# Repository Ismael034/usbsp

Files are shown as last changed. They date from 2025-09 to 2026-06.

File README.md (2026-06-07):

# USBsp

Have you ever tried to plug a USB device into a computer that has USB restrictions enabled? It's frustrating, isn't it? You can't use your USB devices, and you have no way to bypass the restrictions. But what if I told you that you could spoof the USB identifiers so you bypass these restrictions? That's where USBsp comes in.

Here is your solution!

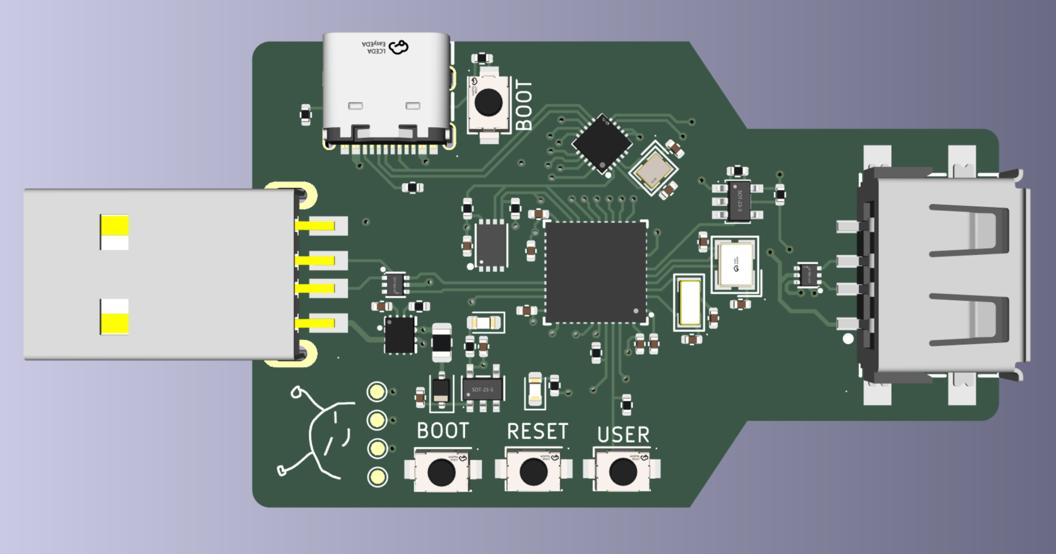
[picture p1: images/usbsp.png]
USBsp hardware


USBsp is a USB device that can spoof the USB identifiers of any device you want. It is based on the CH32V203 and CH572D microcontrollers. With USBsp, you can easily bypass USB restrictions and use your USB devices without any issues.

## Features

- Spoofs basic USB descriptor fields: VID, PID, bcdDevice, manufacturer, product and serial.
- Stores the spoofed descriptor settings in EEPROM.
- WebUSB control panel for changing settings from a Chromium-based browser.
- Can read descriptor-like values from the currently connected downstream USB device and use them as a starting point.
- Basic live packet capture.
- Simple HID keyboard/mouse visualizers.

## Building

The required toolchain is alredy included. It is a custom toolchain made by WCH, downloaded from [here](https://www.mounriver.com/download). This toolchain constains custom targets for their MCUs. Other toolchains (like xpack) have not been tested.

### Clone the repository and add the toolchain to the path

```
git clone https://github.com/Ismael034/usbsp.git
cd usbsp
export PATH=$PWD/toolchain/bin/:$PATH
```

### Configure meson

```
meson setup build-ch32v203 --cross-file ch32v203/ch32v203-cross.ini
meson setup build-ch572d --cross-file ch572d/ch572d-cross.ini
```

### Build with ninja

```
ninja -C build-ch32v203 ch32v203/ch32v203.hex
ninja -C build-ch572d ch572d/ch572d.hex
```

If everything goes well, you'll end up with two .hex files – one for each MCU.

## Flashing

To flash the firmware to your MCU, you can use one of the following tools:

- [WCH-LinkUtility](https://www.wch.cn/downloads/wch-linkutility_zip.html)
- [wlink](https://github.com/ch32-rs/wlink/)
- [OpenOCD](https://openocd.org/)

```
wlink flash ./build-ch32v203/ch32v203/ch32v203.hex
wlink flash ./build-ch572d/ch572d/ch572d.hex
```

## Tests

It is also possible to build a test firmware, which will test hardware funcionality like EEPROM access, USBD, USBH, buttons, etc. You can build it using a predefined custom target.

```
ninja -C build-ch32v203 ch32v203/ch32v203_test.hex
```

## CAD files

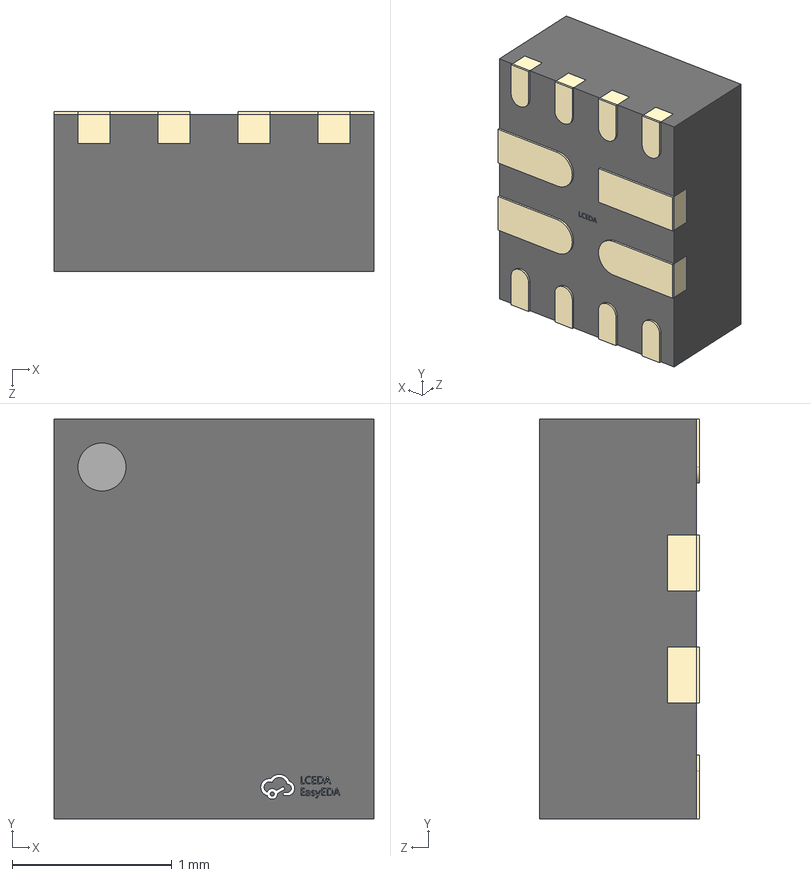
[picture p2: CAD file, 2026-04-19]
hardware/dev/usb_sp_fp_dev/usb_sp_model_dev/VQFN-HR-12_L2.5-W2.0-P0.50-BL.step
2.00 x 2.50 x 1.00 mm

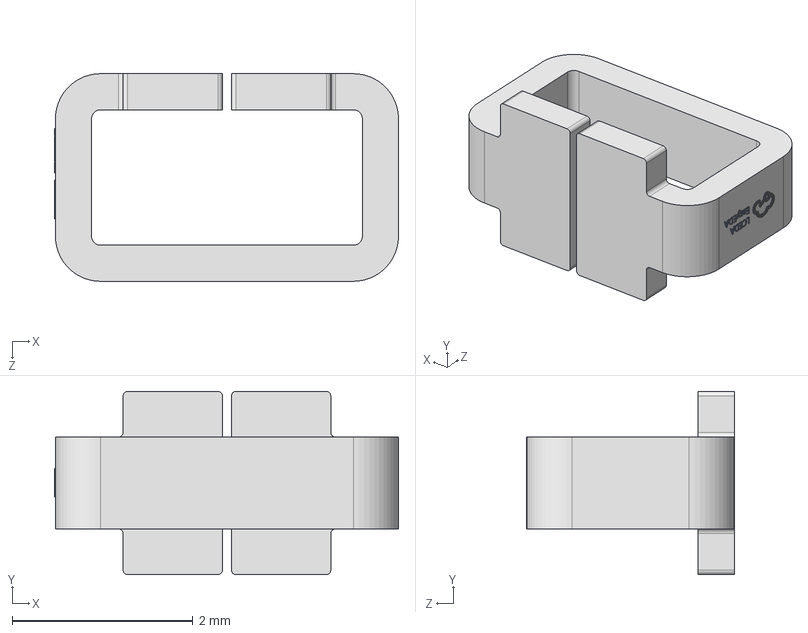
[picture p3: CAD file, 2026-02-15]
hardware/dev/usb_sp_fp_dev/usb_sp_model_dev/TESTPOINT-SMD_L3.8-W2.0_RH-5019.step
3.81 x 2.03 x 2.30 mm

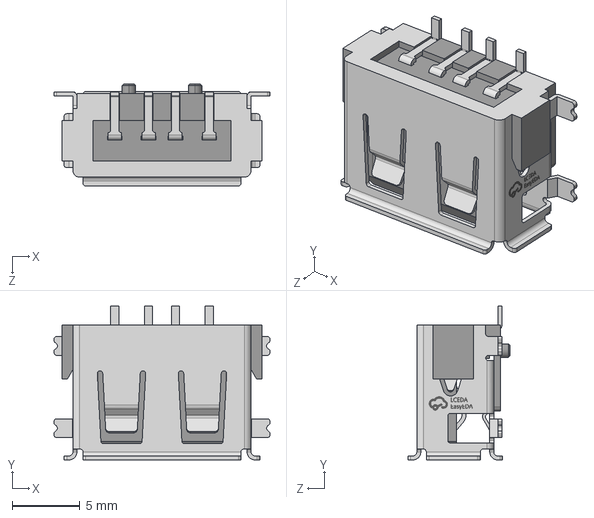
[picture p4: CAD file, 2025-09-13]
hardware/usb_sp_fp/usb_sp_model/USB-A-SMD_10.0-QTJ6.3.step
16.0 x 11.4 x 7.55 mm

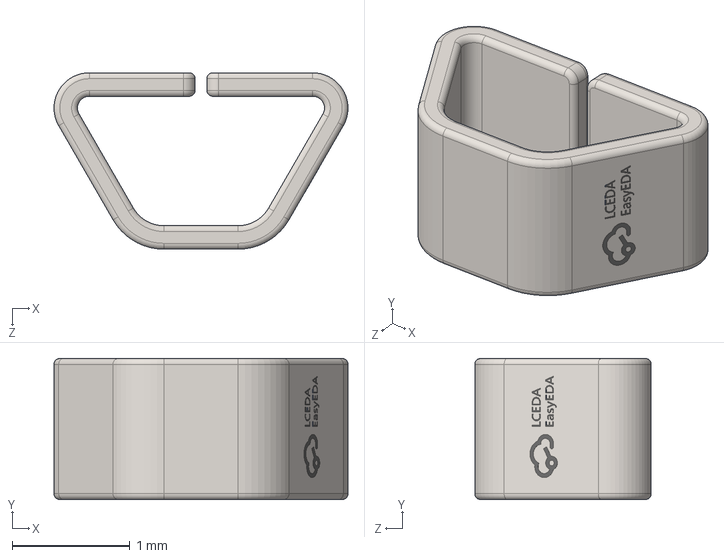
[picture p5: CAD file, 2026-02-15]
hardware/dev/usb_sp_fp_dev/usb_sp_model_dev/SMD_RH-5015.step
2.50 x 1.20 x 1.50 mm

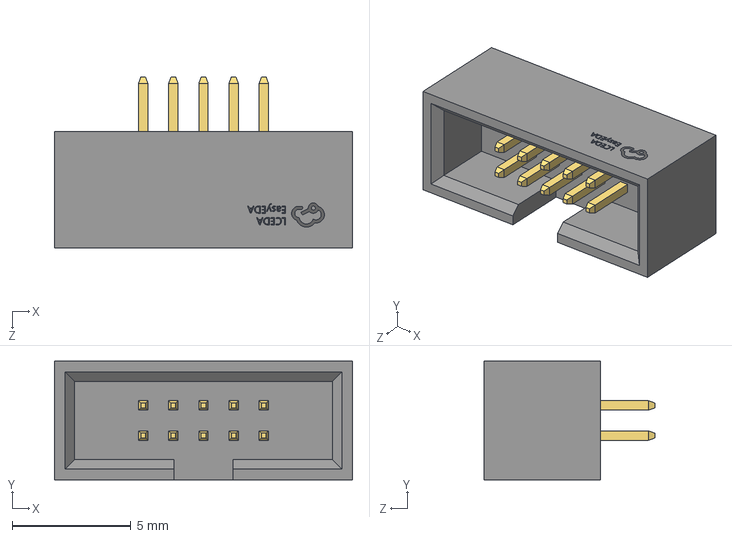
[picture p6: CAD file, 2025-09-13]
hardware/usb_sp_fp/usb_sp_model/CONN-TH_10P-P1.27_HX-JN1.27-2X5P-ZZ-H4.9.step
12.6 x 5.00 x 7.20 mm

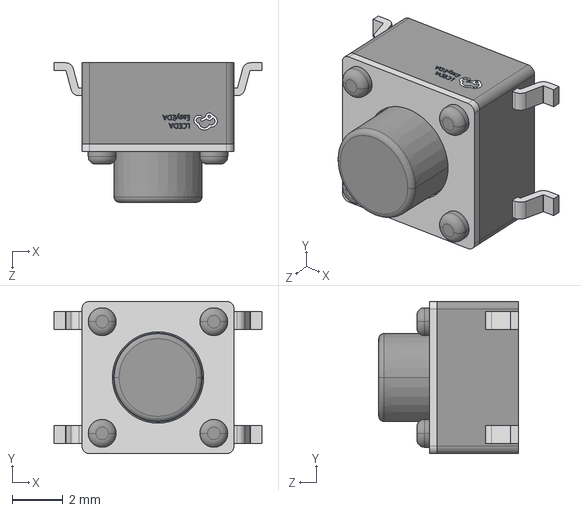
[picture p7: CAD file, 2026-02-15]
hardware/dev/usb_sp_fp_dev/usb_sp_model_dev/SW-SMD_4P-L6.0-W6.0-P4.50-LS8.2.step
8.20 x 6.00 x 5.50 mm

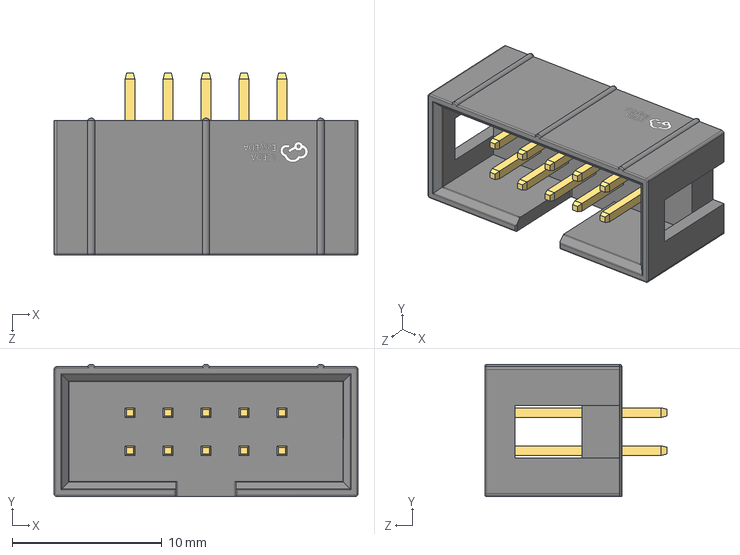
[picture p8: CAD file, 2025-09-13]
hardware/usb_sp_fp/usb_sp_model/IDC-TH_10P-P2.54_C5665.step
20.3 x 8.85 x 12.2 mm

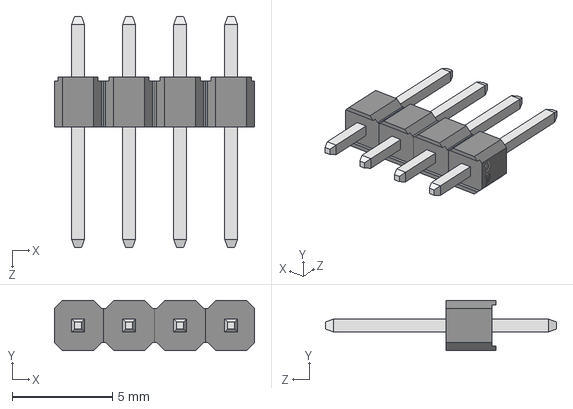
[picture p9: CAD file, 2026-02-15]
hardware/dev/usb_sp_fp_dev/usb_sp_model_dev/HDR-TH_4P-HX-PH254-01-04-Z-L11.5.step
9.97 x 2.50 x 11.5 mm

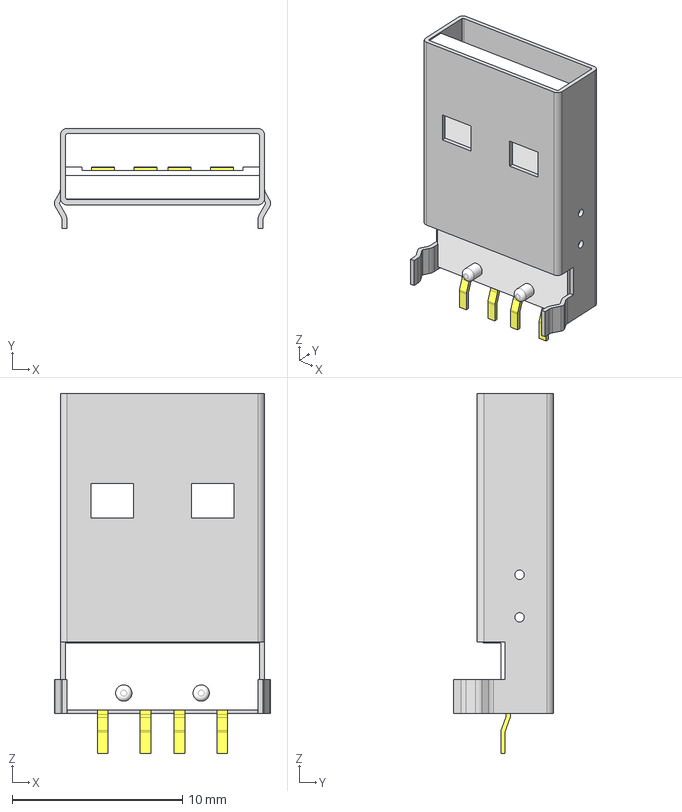
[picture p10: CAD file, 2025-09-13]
hardware/usb_sp_fp/usb_sp_model/USB-A-SMD_917-181A102ES60200.step
12.7 x 5.89 x 21.1 mm
USB-AM-S-SM1_S
USB-AM-S-W-SM1_B
USB-AM-S-SM1_P

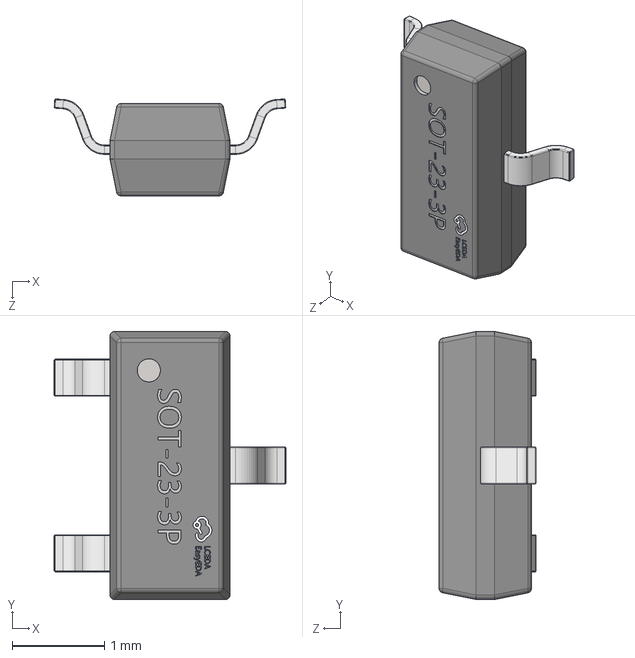
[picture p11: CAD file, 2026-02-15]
hardware/dev/usb_sp_fp_dev/usb_sp_model_dev/SOT-23-3_L2.9-W1.3-P1.90-LS2.4-BR.step
2.51 x 2.90 x 1.05 mm

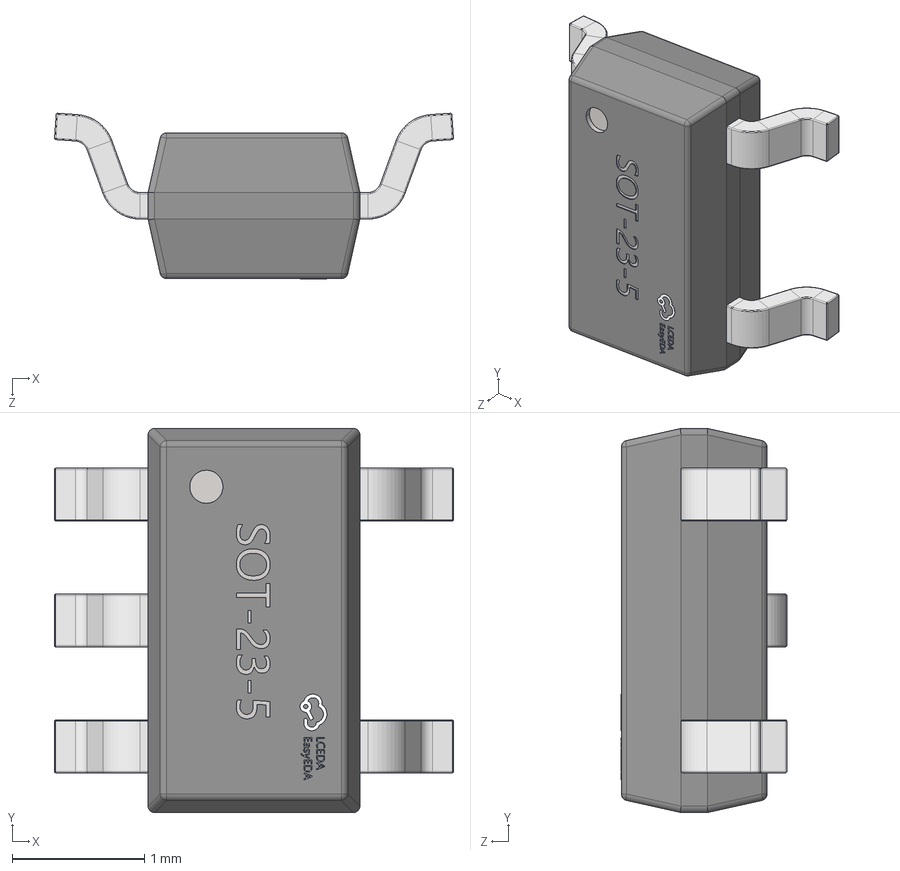
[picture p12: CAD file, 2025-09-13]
hardware/usb_sp_fp/usb_sp_model/SOT-23-5_L3.0-W1.7-P0.95-LS2.8-BL.step
3.01 x 2.90 x 1.25 mm

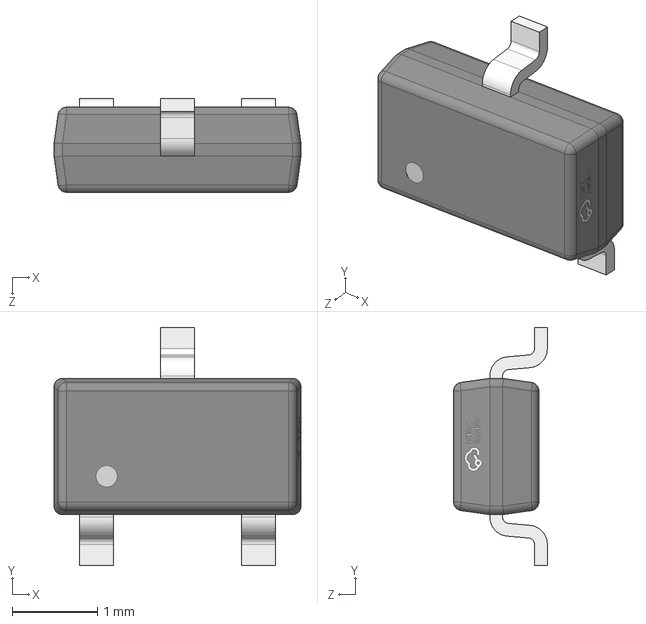
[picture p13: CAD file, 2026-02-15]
hardware/dev/usb_sp_fp_dev/usb_sp_model_dev/SOT-23-3_L2.9-W1.6-P1.90-LS2.8-BR.step
2.90 x 2.80 x 1.10 mm

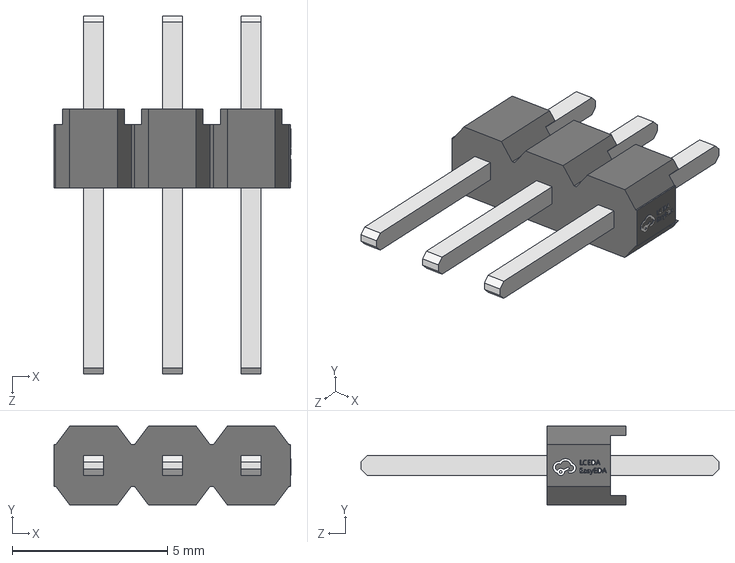
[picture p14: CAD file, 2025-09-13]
hardware/usb_sp_fp/usb_sp_model/HDR-TH_3P-P2.54-V-M.step
7.63 x 2.54 x 11.5 mm

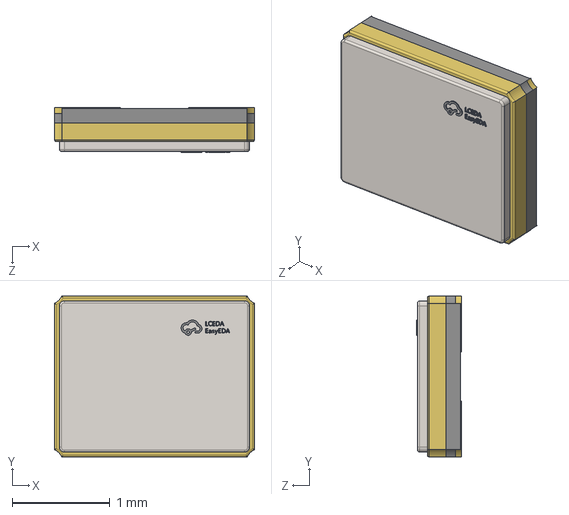
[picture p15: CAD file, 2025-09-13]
hardware/usb_sp_fp/usb_sp_model/CRYSTAL-SMD_4P-L2.0-W1.6-BL.step
2.05 x 1.65 x 0.46 mm

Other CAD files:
hardware/usb_sp_fp/usb_sp_model/SOT-666-6_L1.6-W1.2-P0.50-LS1.6-BL.step
hardware/usb_sp_fp/usb_sp_model/USB-C-SMD_KH-TYPE-C-16P.step
hardware/usb_sp_fp/usb_sp_model/CRYSTAL-SMD_4P-L3.2-W2.5-BL.step
hardware/usb_sp_fp/usb_sp_model/CRYSTAL-SMD_L3.2-W1.5-1.step
hardware/usb_sp_fp/usb_sp_model/OSC-SMD_4P-L3.2-W2.5-BL.step
hardware/usb_sp_fp/usb_sp_model/QFN-20_L3.0-W3.0-P0.40-TL-EP1.7.step
hardware/usb_sp_fp/usb_sp_model/SW-SMD_L3.9-W3.0-P4.45.step
hardware/usb_sp_fp/usb_sp_model/TQFN-48_L7.0-W7.0-P0.50-BL-EP5.5.step
hardware/usb_sp_fp/usb_sp_model/UDFN-8_L3.0-W2.0-P0.50-BL-EP-3.step

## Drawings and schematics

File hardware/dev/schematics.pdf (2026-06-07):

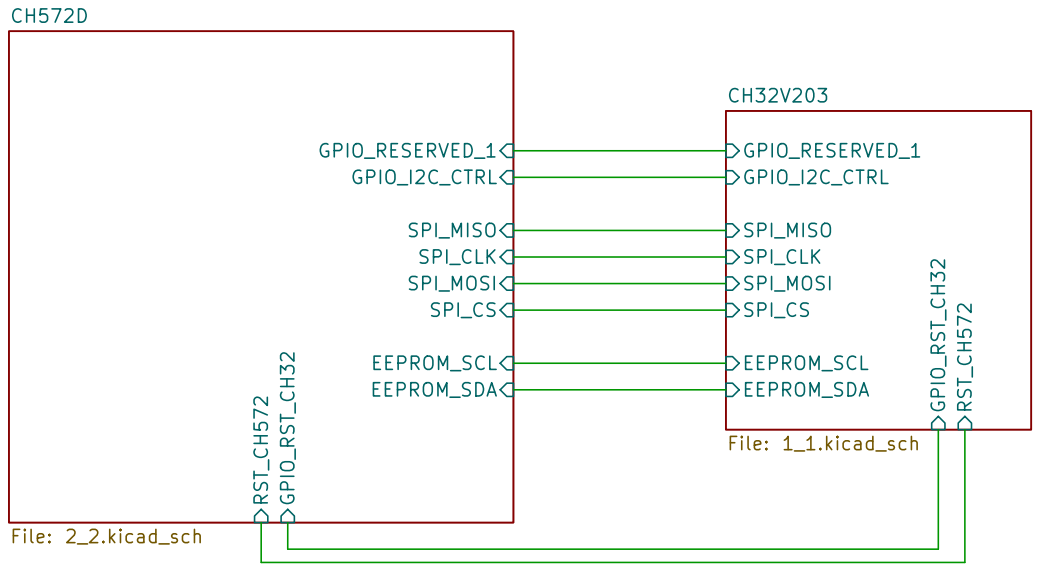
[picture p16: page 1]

Size: A4 | Rev:
KiCad E.D.A. 10.0.3 | Id: 3/3

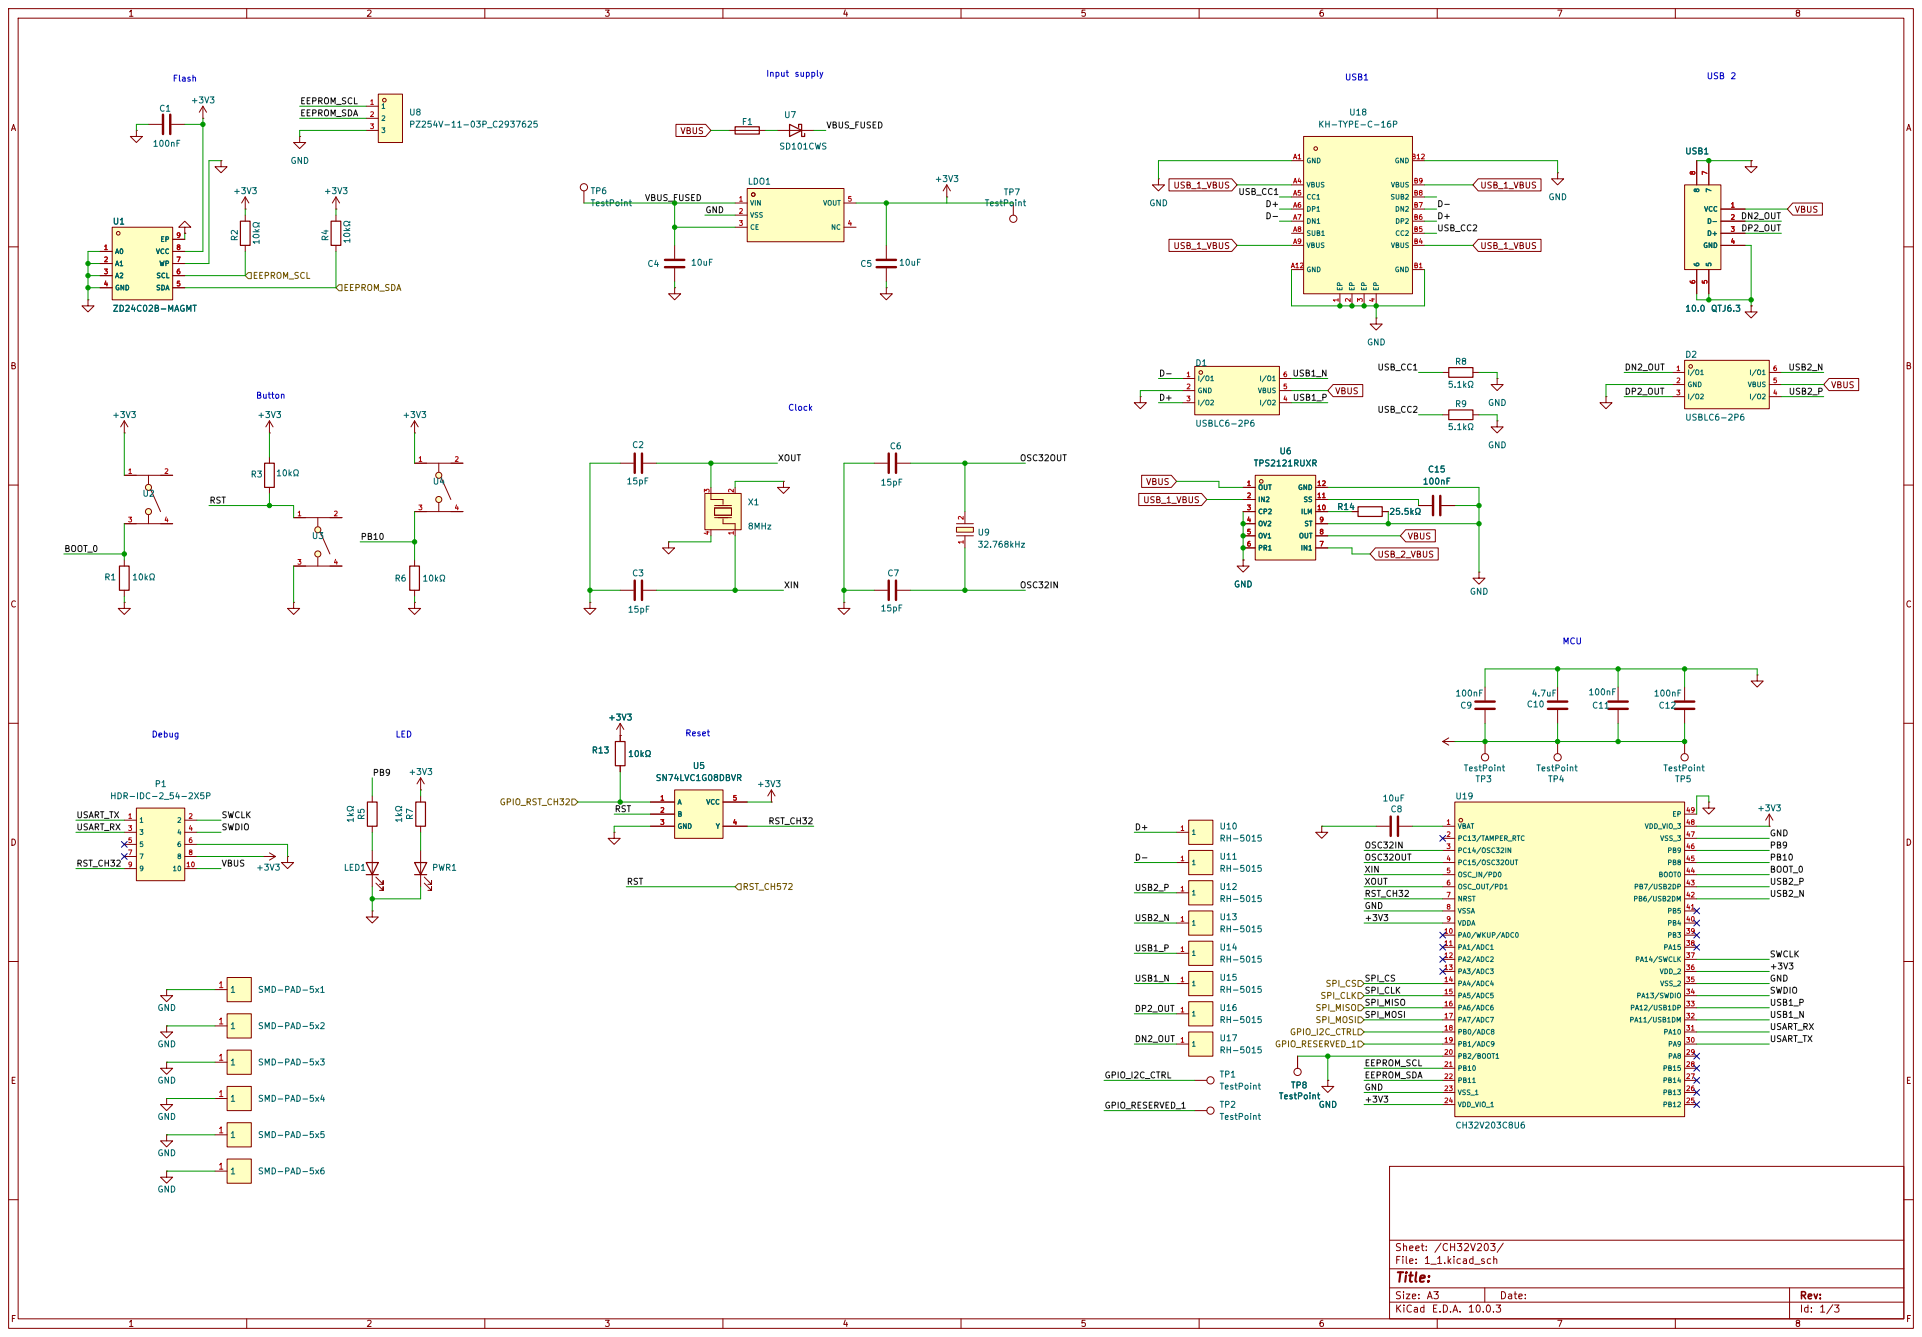
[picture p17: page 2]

Input supply Clock Button Debug
Flash

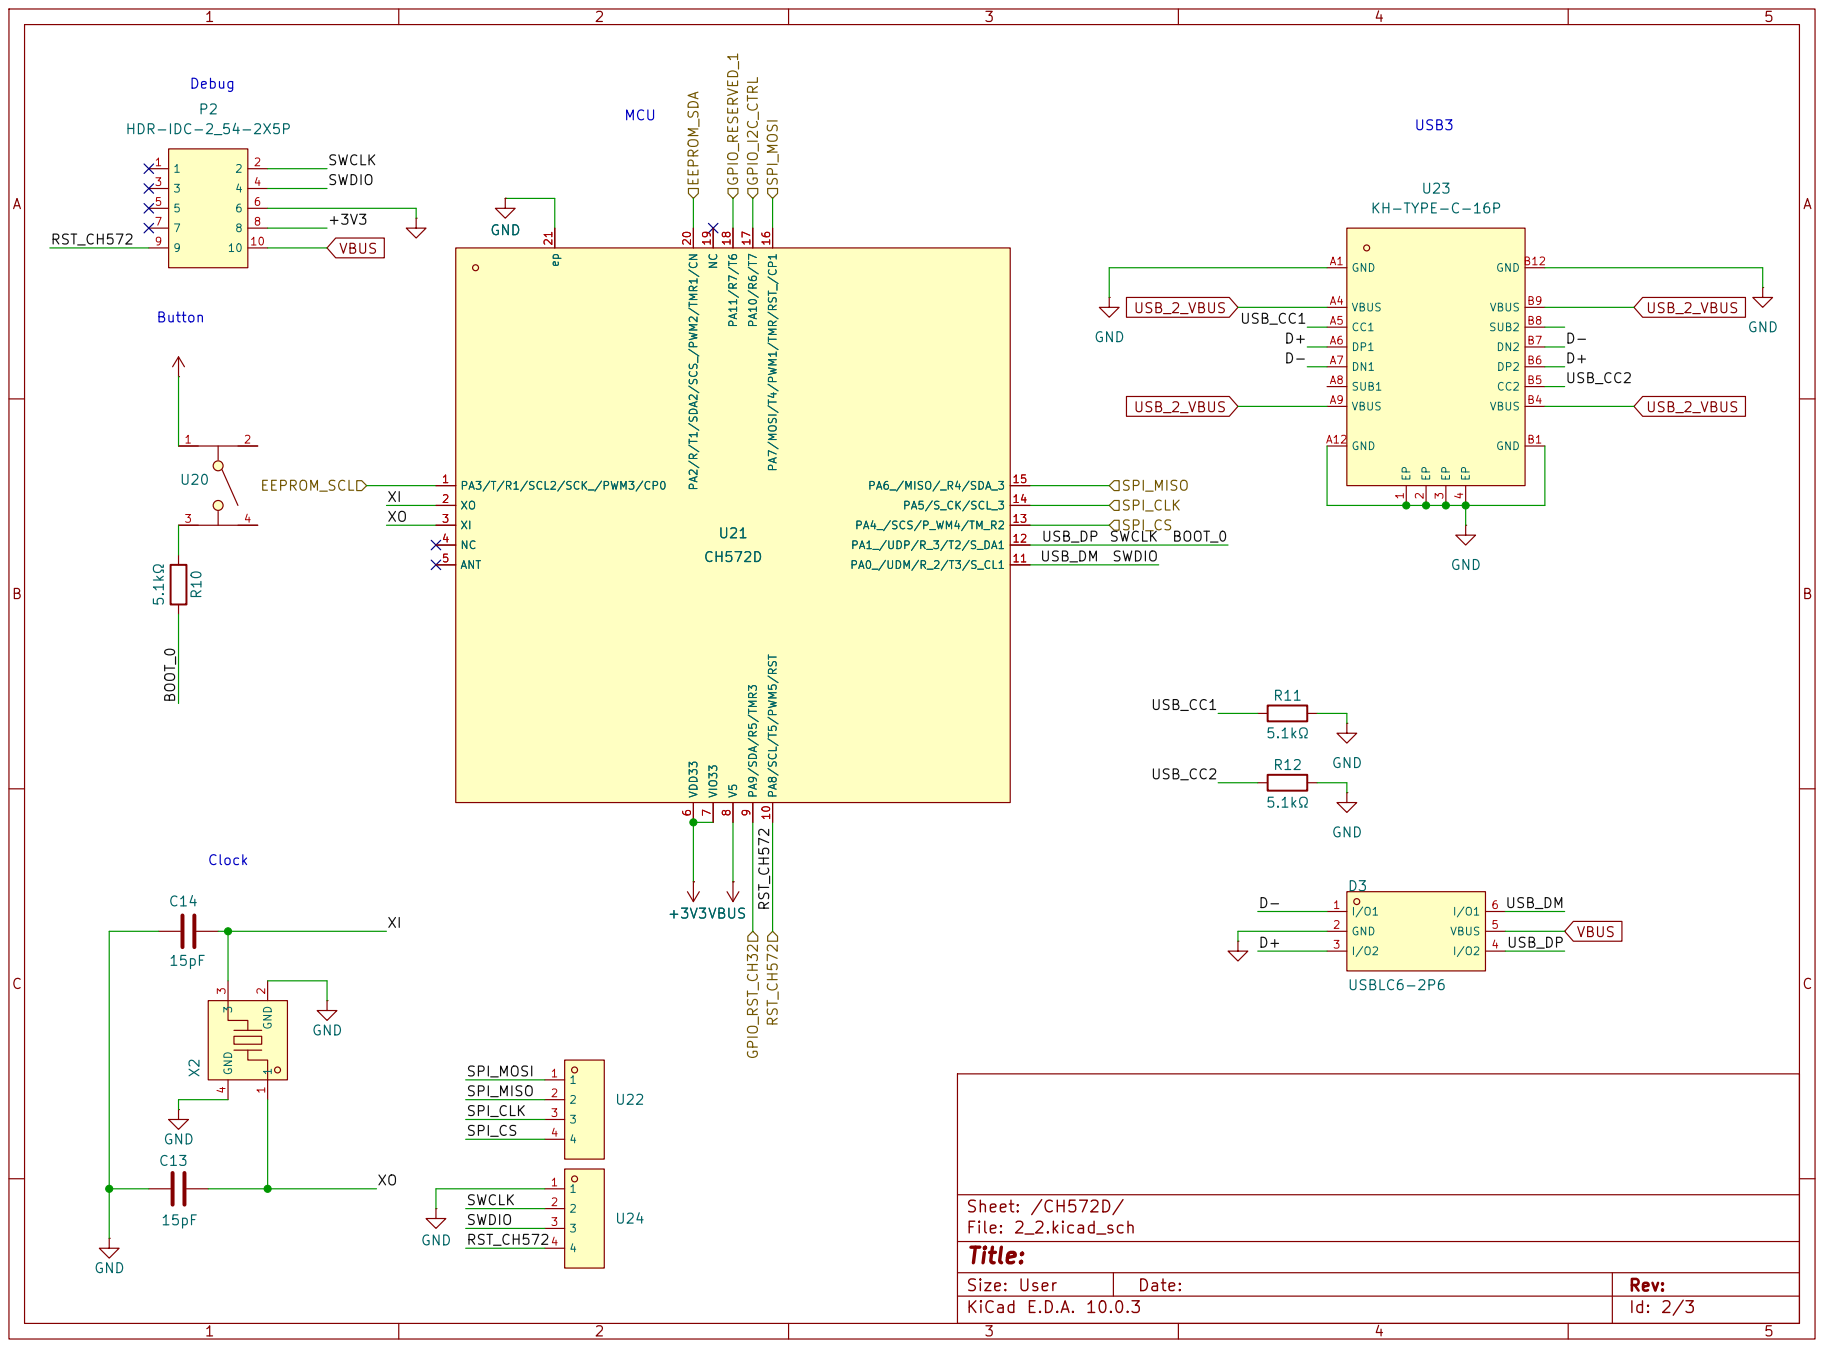
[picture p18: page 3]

9 PA8/SCL/T5/PWM5/RST 10 PA0_/UDM/R_2/T3/S_CL1 11 PA1_/UDP/R_3/T2/S_DA1 12 PA4_/SCS/P_WM4/TM_R2 13 PA5/S_CK/SCL_3 14 PA6_/MISO/_R4/SDA_3 15 PA7/MOSI/T4/PWM1/TMR/RST_/CP1 16 PA10/R6/T7 17 PA11/R7/T6 18 NC 19 PA2/R/T1/SDA2/SCS_/PWM2/TMR1/CN 20 ep 21GND

9 PA8/SCL/T5/PWM5/RST 10 PA0_/UDM/R_2/T3/S_CL1 11 PA1_/UDP/R_3/T2/S_DA1 12 PA4_/SCS/P_WM4/TM_R2 13 PA5/S_CK/SCL_3 14 PA6_/MISO/_R4/SDA_3 15 PA7/MOSI/T4/PWM1/TMR/RST_/CP1 16 PA10/R6/T7 17 PA11/R7/T6 18 NC 19 PA2/R/T1/SDA2/SCS_/PWM2/TMR1/CN 20 ep 21 U21 CH572D

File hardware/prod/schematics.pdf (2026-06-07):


Size: A4 | Rev:
KiCad E.D.A. 10.0.3 | Id: 3/3

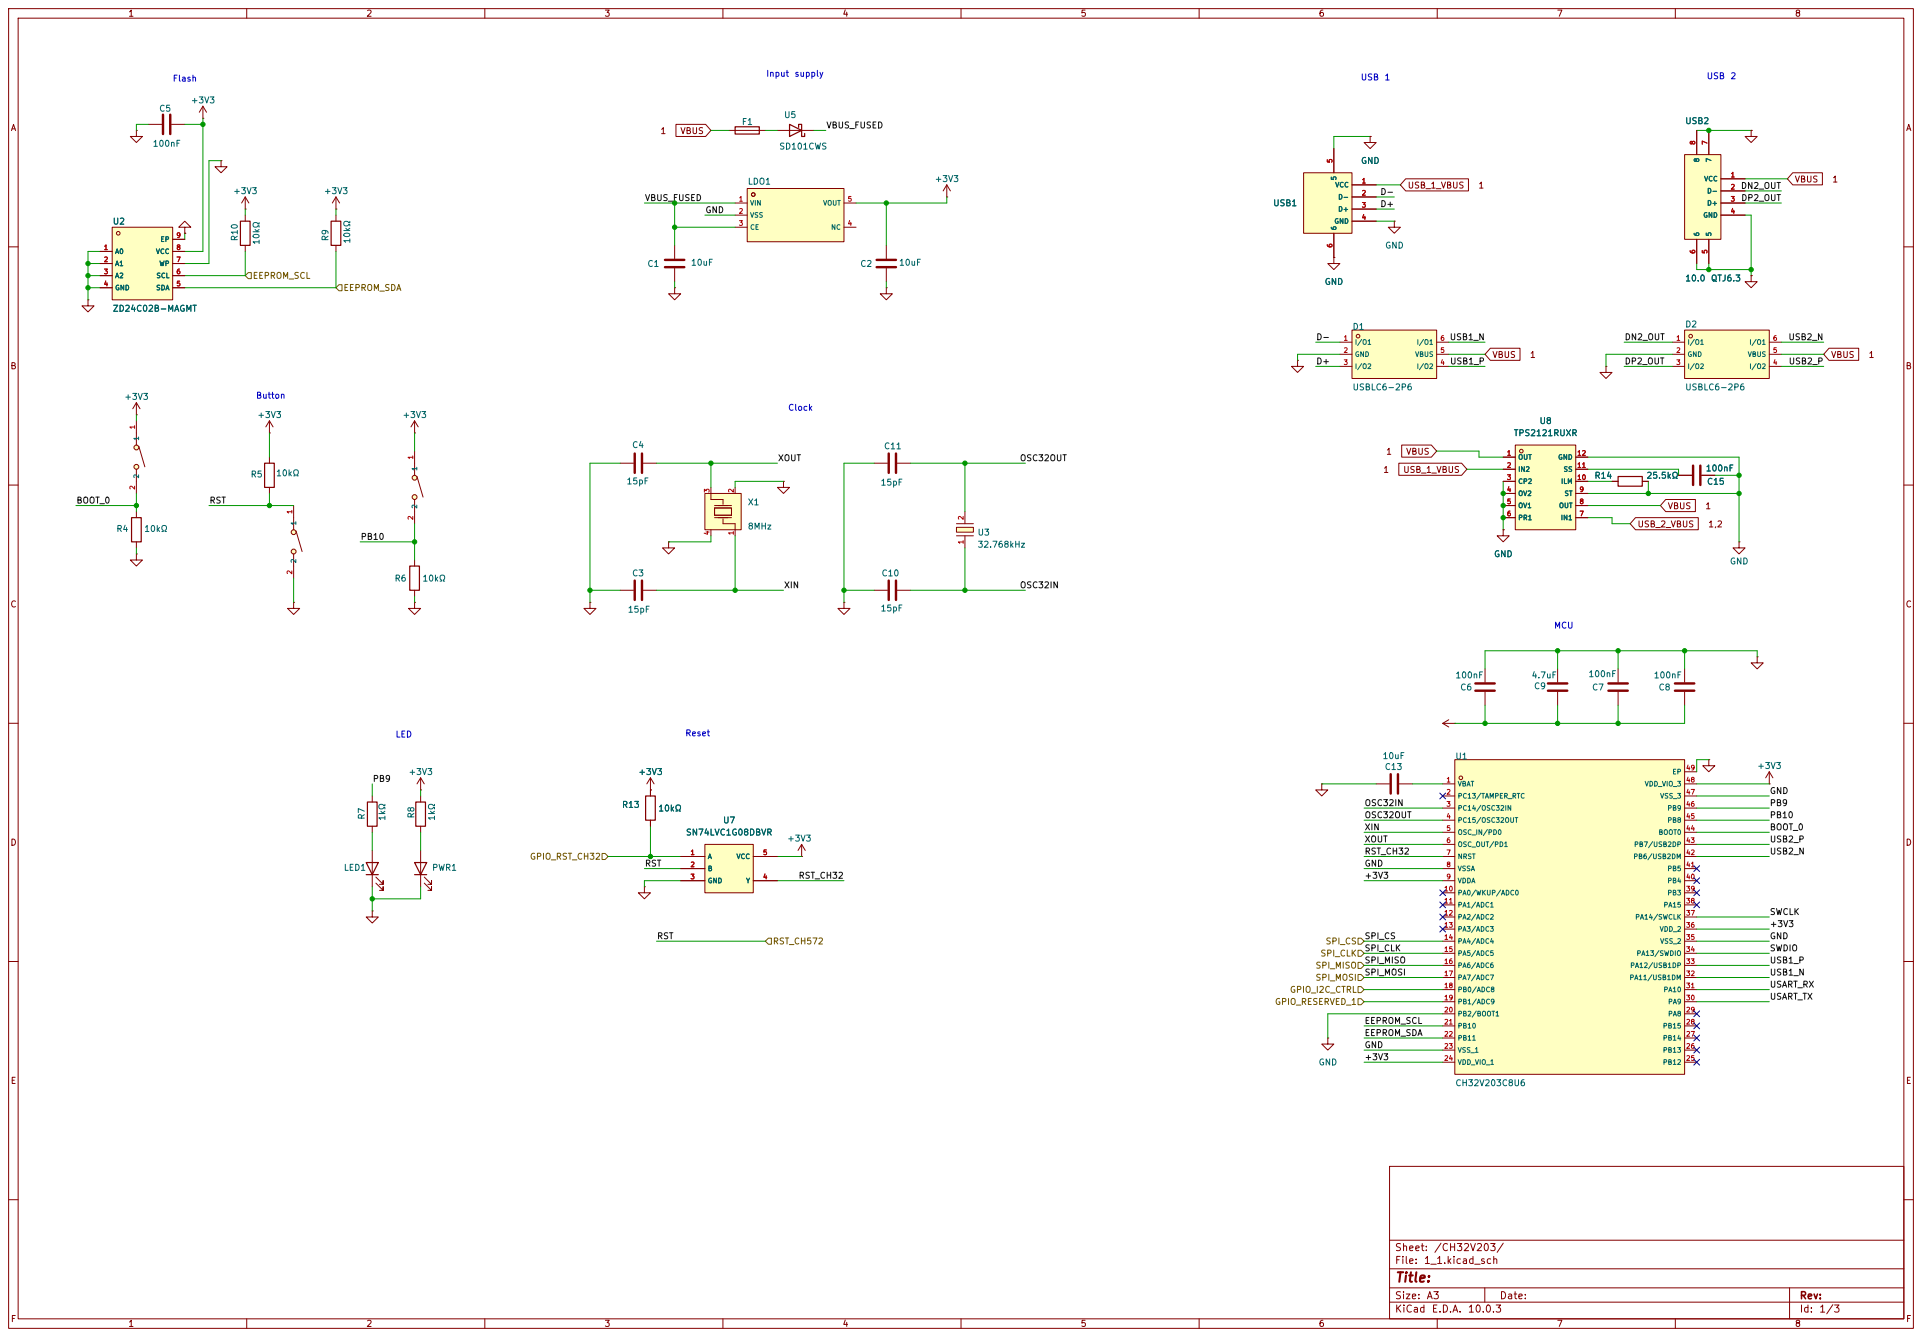
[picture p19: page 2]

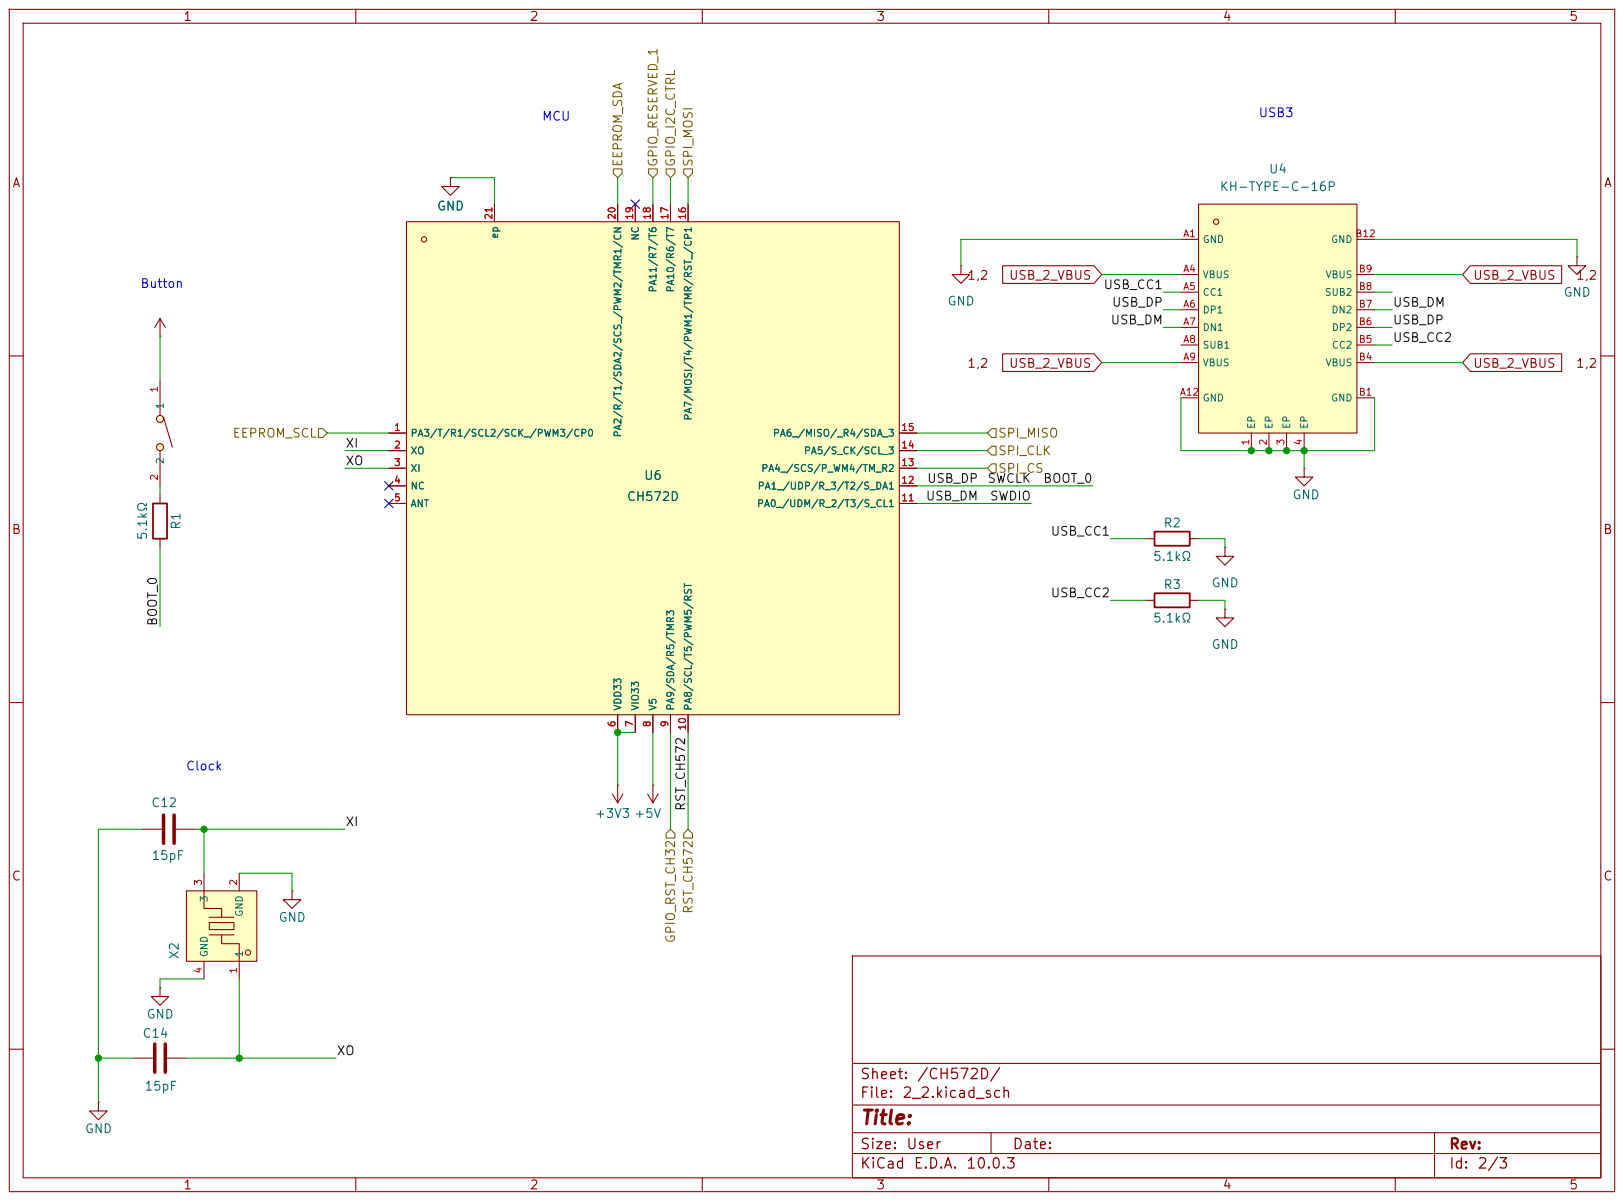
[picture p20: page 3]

9 PA8/SCL/T5/PWM5/RST 10 PA0_/UDM/R_2/T3/S_CL1 11 PA1_/UDP/R_3/T2/S_DA1 12 PA4_/SCS/P_WM4/TM_R2 13 PA5/S_CK/SCL_3 14 PA6_/MISO/_R4/SDA_3 15 PA7/MOSI/T4/PWM1/TMR/RST_/CP1 16 PA10/R6/T7 17 PA11/R7/T6 18 NC 19 PA2/R/T1/SDA2/SCS_/PWM2/TMR1/CN 20 ep 21GND

9 PA8/SCL/T5/PWM5/RST 10 PA0_/UDM/R_2/T3/S_CL1 11 PA1_/UDP/R_3/T2/S_DA1 12 PA4_/SCS/P_WM4/TM_R2 13 PA5/S_CK/SCL_3 14 PA6_/MISO/_R4/SDA_3 15 PA7/MOSI/T4/PWM1/TMR/RST_/CP1 16 PA10/R6/T7 17 PA11/R7/T6 18 NC 19 PA2/R/T1/SDA2/SCS_/PWM2/TMR1/CN 20 ep 21 U6 CH572D GND +3V3 GND

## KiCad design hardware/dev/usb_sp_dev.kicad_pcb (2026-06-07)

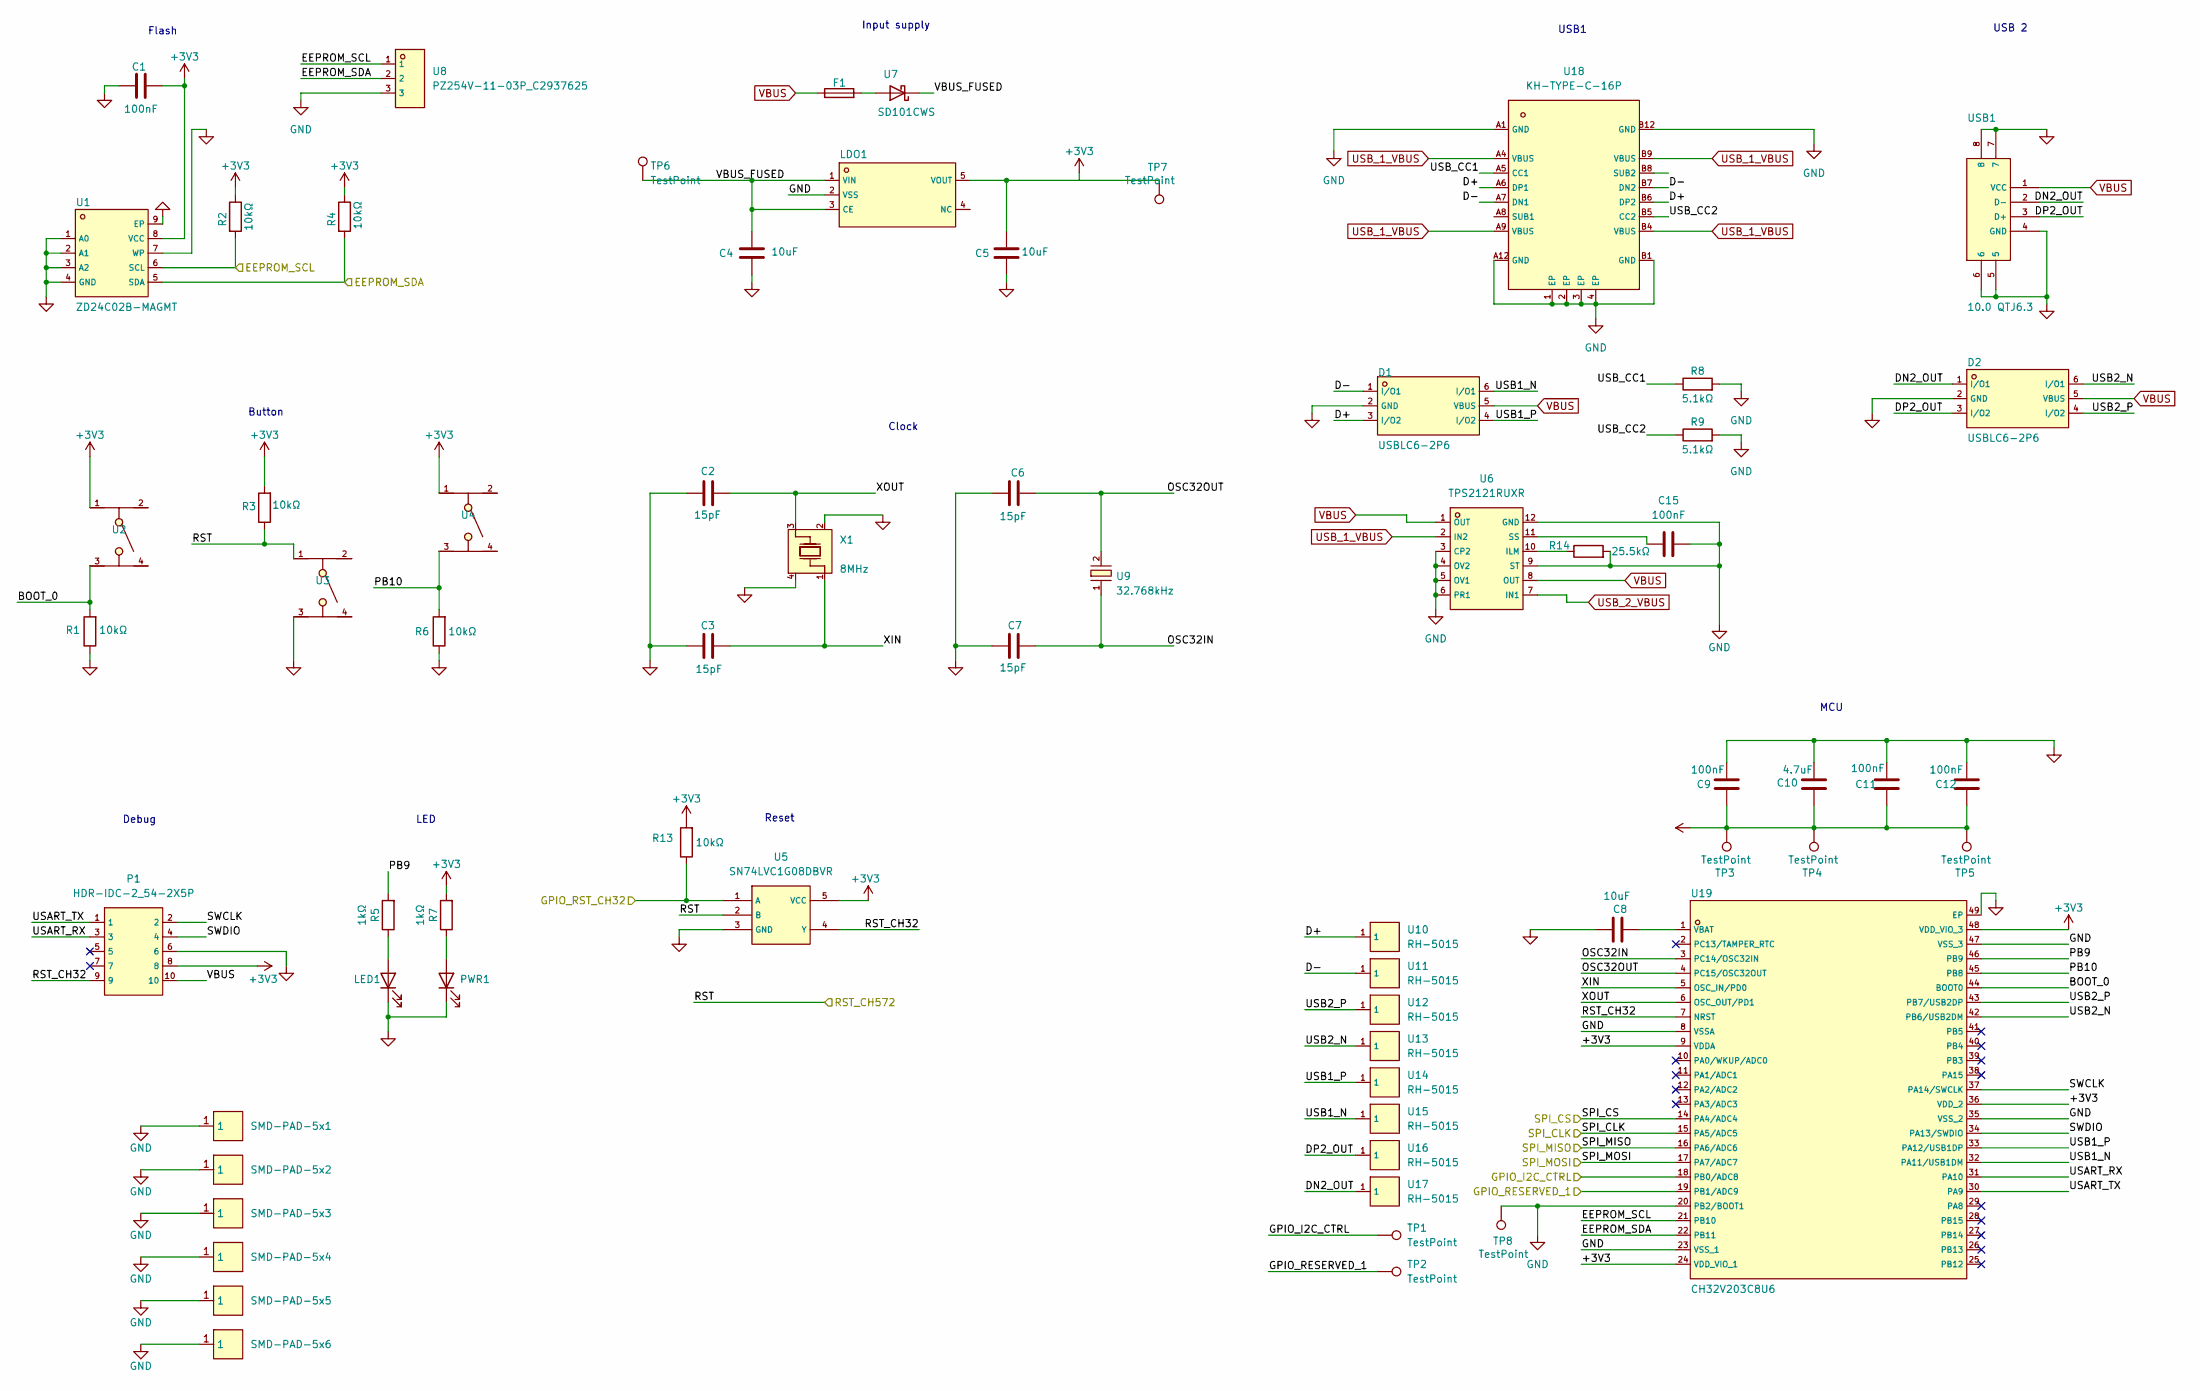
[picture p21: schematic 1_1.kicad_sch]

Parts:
C1: 100nF; C_0402_1005Metric; Manufacturer Part CL05B104KO5NNNC; LCSC Part Name 100nF ±10% 16V
C2, C3, C6, C7: 15pF; C_0402_1005Metric; Manufacturer Part 0402CG150J500NT; LCSC Part Name 15pF ±5% 50V
C4, C5, C8: 10uF; C_0603_1608Metric; Voltage Rating 10V; Manufacturer Part CGA0603X5R106K100JT; LCSC Part Name 10uF ±10% 10V
C9, C11, C12: 100nF; C_0603_1608Metric; Manufacturer Part CGA0603X7R104K500JT; LCSC Part Name 100nF ±10% 50V
C10: 4.7uF; C_0603_1608Metric; Manufacturer Part CL10A475KP8NNNC; LCSC Part Name 4.7uF ±10% 10V
C15: 100nF; C_0603_1608Metric
D1, D2: USBLC6-2P6; SOT-666-6_L1.6-W1.2-P0.50-LS1.6-BL; Manufacturer Part USBLC6-2P6; LCSC Part Name MSL=3
F1: JK-SMD0805-020-30V; Fuse_0805_2012Metric; Manufacturer Part JK-SMD0805-020-30V; LCSC Part Name 30V 200mA 0805自恢复
LDO1: ME6211C33M5G-N; SOT-23-5_L3.0-W1.7-P0.95-LS2.8-BL; Manufacturer Part ME6211C33M5G-N; LCSC Part Name 输入6V 输出3.3V 500mA
LED1: XL-1608UGC-04; LED_0603_1608Metric; Manufacturer Part XL-1608UGC-04; LCSC Part Name XL-1608UGC-04
P1: HDR-IDC-2_54-2X5P; IDC-TH_10P-P2.54_C5665; LCSC C5665
PWR1: NCD0603R1; LED_0603_1608Metric; Manufacturer Part NCD0603R1; LCSC Part Name NCD0603R1
R1, R2, R3, R4, R6, R13: 10kΩ; R_0603_1608Metric; Manufacturer Part RC0603JR-0710KL; LCSC Part Name 厚膜电阻 10kΩ ±5% 100mW
R5, R7: 1kΩ; R_0603_1608Metric
R8, R9: 5.1kΩ; R_0603_1608Metric
R14: 25.5kΩ; R_0603_1608Metric
SMD-PAD-5x1, SMD-PAD-5x2, SMD-PAD-5x3, SMD-PAD-5x4, SMD-PAD-5x5, SMD-PAD-5x6: SMD-PAD-5x5
TP1, TP2, TP3, TP4, TP5, TP6, TP7, TP8: TestPoint; TestPoint_Pad_D1.0mm
U1: ZD24C02B-MAGMT; UDFN-8_L3.0-W2.0-P0.50-BL-EP-3; Manufacturer Part ZD24C02B-MAGMT; LCSC Part Name 2Kbit I2C兼容串行EEPROM
U2, U3, U4: TC-6601-5_0-260-8_3; SW-SMD_4P-L6.0-W6.0-P4.50-LS8.2; Manufacturer Part TS-1088-AR02016; LCSC Part Name 4*3*2mm 立贴 轻触开关
U5: SN74LVC1G08DBVR; SOT-23-5_L3.0-W1.7-P0.95-LS2.8-BR; LCSC C7666
U6: TPS2121RUXR; VQFN-HR-12_L2.5-W2.0-P0.50-BL; LCSC C485916
U7: SD101CWS; D_SOD-323; Manufacturer Part SD101CWS; LCSC Part Name SD101CWS
U8: PZ254V-11-03P_C2937625; HDR-TH_3P-P2.54-V-M; LCSC C2937625
U9: 32.768kHz; CRYSTAL-SMD_L3.2-W1.5-1; Manufacturer Part H31003271C2070CY; LCSC Part Name 32.768kHz ±20ppm 12.5pF
U10, U11, U12, U13, U14, U15, U16, U17: RH-5015; SMD_RH-5015; LCSC C5199798
U18: KH-TYPE-C-16P; USB-C-SMD_KH-TYPE-C-16P; LCSC C709357
U19: CH32V203C8U6; TQFN-48_L7.0-W7.0-P0.50-BL-EP5.5; Manufacturer Part CH32V203C8U6; LCSC Part Name CH32V203C8U6
USB1: 10.0 QTJ6.3; USB-A-SMD_10.0-QTJ6.3; Manufacturer Part 10.0 QTJ6.3; LCSC Part Name Type-A 母 卧贴
X1: 8MHz; CRYSTAL-SMD_4P-L3.2-W2.5-BL; Manufacturer Part TAXM8M4RDBCCT2T; LCSC Part Name 8MHz ±10ppm 10pF

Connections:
+3V3: C1.1, C5.2, C9.1, C10.1, C11.1, C12.1, LDO1.5 (VOUT), P1.8, R2.1, R3.2, R4.1, R7.2, R13.2, TP3.1 (1_1), TP4.1 (1_1), TP5.1 (1_1), TP7.1 (1_1), U1.8 (VCC), U2.1, U4.1, U5.5 (VCC), U19.9 (VDDA), U19.24 (VDD_VIO_1), U19.36 (VDD_2), U19.48 (VDD_VIO_3); also elsewhere on the board
/CH32V203/BOOT_0: R1.2, U2.3, U19.44 (BOOT0)
/CH32V203/D+: D1.3 (I/O2), U10.1 (1_1), U18.A6 (DP1), U18.B6 (DP2)
/CH32V203/D-: D1.1 (I/O1), U11.1 (1_1), U18.A7 (DN1), U18.B7 (DN2)
/CH32V203/DN2_OUT: D2.1 (I/O1), U17.1 (1_1), USB1.2 (D-)
/CH32V203/DP2_OUT: D2.3 (I/O2), U16.1 (1_1), USB1.3 (D+)
/CH32V203/EEPROM_SCL: R2.2, U1.6 (SCL), U8.1, U19.21 (PB10); also elsewhere on the board
/CH32V203/EEPROM_SDA: R4.2, U1.5 (SDA), U8.2, U19.22 (PB11); also elsewhere on the board
/CH32V203/GPIO_I2C_CTRL: TP1.1 (1_1), U19.18 (PB0/ADC8); also elsewhere on the board
/CH32V203/GPIO_RESERVED_1: TP2.1 (1_1), U19.19 (PB1/ADC9); also elsewhere on the board
/CH32V203/GPIO_RST_CH32: R13.1, U5.1 (A); also elsewhere on the board
/CH32V203/OSC32IN: C7.2, U9.1, U19.3 (PC14/OSC32IN)
/CH32V203/OSC32OUT: C6.1, U9.2, U19.4 (PC15/OSC32OUT)
/CH32V203/PB9: R5.2, U19.46 (PB9)
/CH32V203/PB10: R6.2, U4.3, U19.45 (PB8)
/CH32V203/RST: R3.1, U3.1, U5.2 (B); also elsewhere on the board
/CH32V203/RST_CH32: P1.9, U5.4 (Y), U19.7 (NRST)
/CH32V203/SPI_CLK: U19.15 (PA5/ADC5); also elsewhere on the board
/CH32V203/SPI_CS: U19.14 (PA4/ADC4); also elsewhere on the board
/CH32V203/SPI_MISO: U19.16 (PA6/ADC6); also elsewhere on the board
/CH32V203/SPI_MOSI: U19.17 (PA7/ADC7); also elsewhere on the board
/CH32V203/SWCLK: P1.2, U19.37 (PA14/SWCLK)
/CH32V203/SWDIO: P1.4, U19.34 (PA13/SWDIO)
/CH32V203/USART_RX: P1.3, U19.31 (PA10)
/CH32V203/USART_TX: P1.1, U19.30 (PA9)
/CH32V203/USB1_N: D1.6 (I/O1), U15.1 (1_1), U19.32 (PA11/USB1DM)
/CH32V203/USB1_P: D1.4 (I/O2), U14.1 (1_1), U19.33 (PA12/USB1DP)
/CH32V203/USB2_N: D2.6 (I/O1), U13.1 (1_1), U19.42 (PB6/USB2DM)
/CH32V203/USB2_P: D2.4 (I/O2), U12.1 (1_1), U19.43 (PB7/USB2DP)
/CH32V203/USB_CC1: R8.1, U18.A5 (CC1)
/CH32V203/USB_CC2: R9.1, U18.B5 (CC2)
/CH32V203/VBUS_FUSED: C4.2, LDO1.1 (VIN), LDO1.3 (CE), TP6.1 (1_1), U7.1 (K)
/CH32V203/XIN: C3.2, U19.5 (OSC_IN/PD0), X1.1
/CH32V203/XOUT: C2.1, U19.6 (OSC_OUT/PD1), X1.3
GND: C1.2, C2.2, C3.1, C4.1, C5.1, C6.2, C7.1, C8.2, C9.2, C10.2, C11.2, C12.2, C15.2, D1.2 (GND), D2.2 (GND), LDO1.2 (VSS), LED1.1 (K), P1.6, PWR1.1 (K), R1.1, R6.1, R8.2, R9.2, R14.2, SMD-PAD-5x1.1 (1_1), SMD-PAD-5x2.1 (1_1), SMD-PAD-5x3.1 (1_1), SMD-PAD-5x4.1 (1_1), SMD-PAD-5x5.1 (1_1), SMD-PAD-5x6.1 (1_1), TP8.1 (1_1), U1.1 (A0), U1.2 (A1), U1.3 (A2), U1.4 (GND), U1.7 (WP), U1.9 (EP), U3.3, U5.3 (GND), U6.3 (CP2), U6.4 (OV2), U6.5 (OV1), U6.6 (PR1), U6.9 (ST), U6.12 (GND), U8.3, U18.1 (EP), U18.2 (EP), U18.3 (EP), U18.4 (EP), U18.A1 (GND), U18.A12 (GND), U18.B1 (GND), U18.B12 (GND), U19.8 (VSSA), U19.20 (PB2/BOOT1), U19.23 (VSS_1), U19.35 (VSS_2), U19.47 (VSS_3), U19.49 (EP), USB1.4 (GND), USB1.5, USB1.6, USB1.7, USB1.8, X1.2, X1.4; also elsewhere on the board
unnamed: LED1.2 (A), R5.1
unnamed: PWR1.2 (A), R7.1
unnamed: R14.1, U6.10 (ILM)
unnamed: C15.1, U6.11 (SS)
unnamed: F1.2, U7.2 (A)
unnamed: C8.1, U19.1 (VBAT)
USB_1_VBUS: U6.2 (IN2), U18.A4 (VBUS), U18.A9 (VBUS), U18.B4 (VBUS), U18.B9 (VBUS)
USB_2_VBUS: U6.7 (IN1); also elsewhere on the board
VBUS: D1.5 (VBUS), D2.5 (VBUS), F1.1, P1.10, U6.1 (OUT), U6.8 (OUT), USB1.1 (VCC); also elsewhere on the board

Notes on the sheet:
Reset
Debug
Clock
Button
USB1
Flash
Input supply
USB 2
LED
MCU

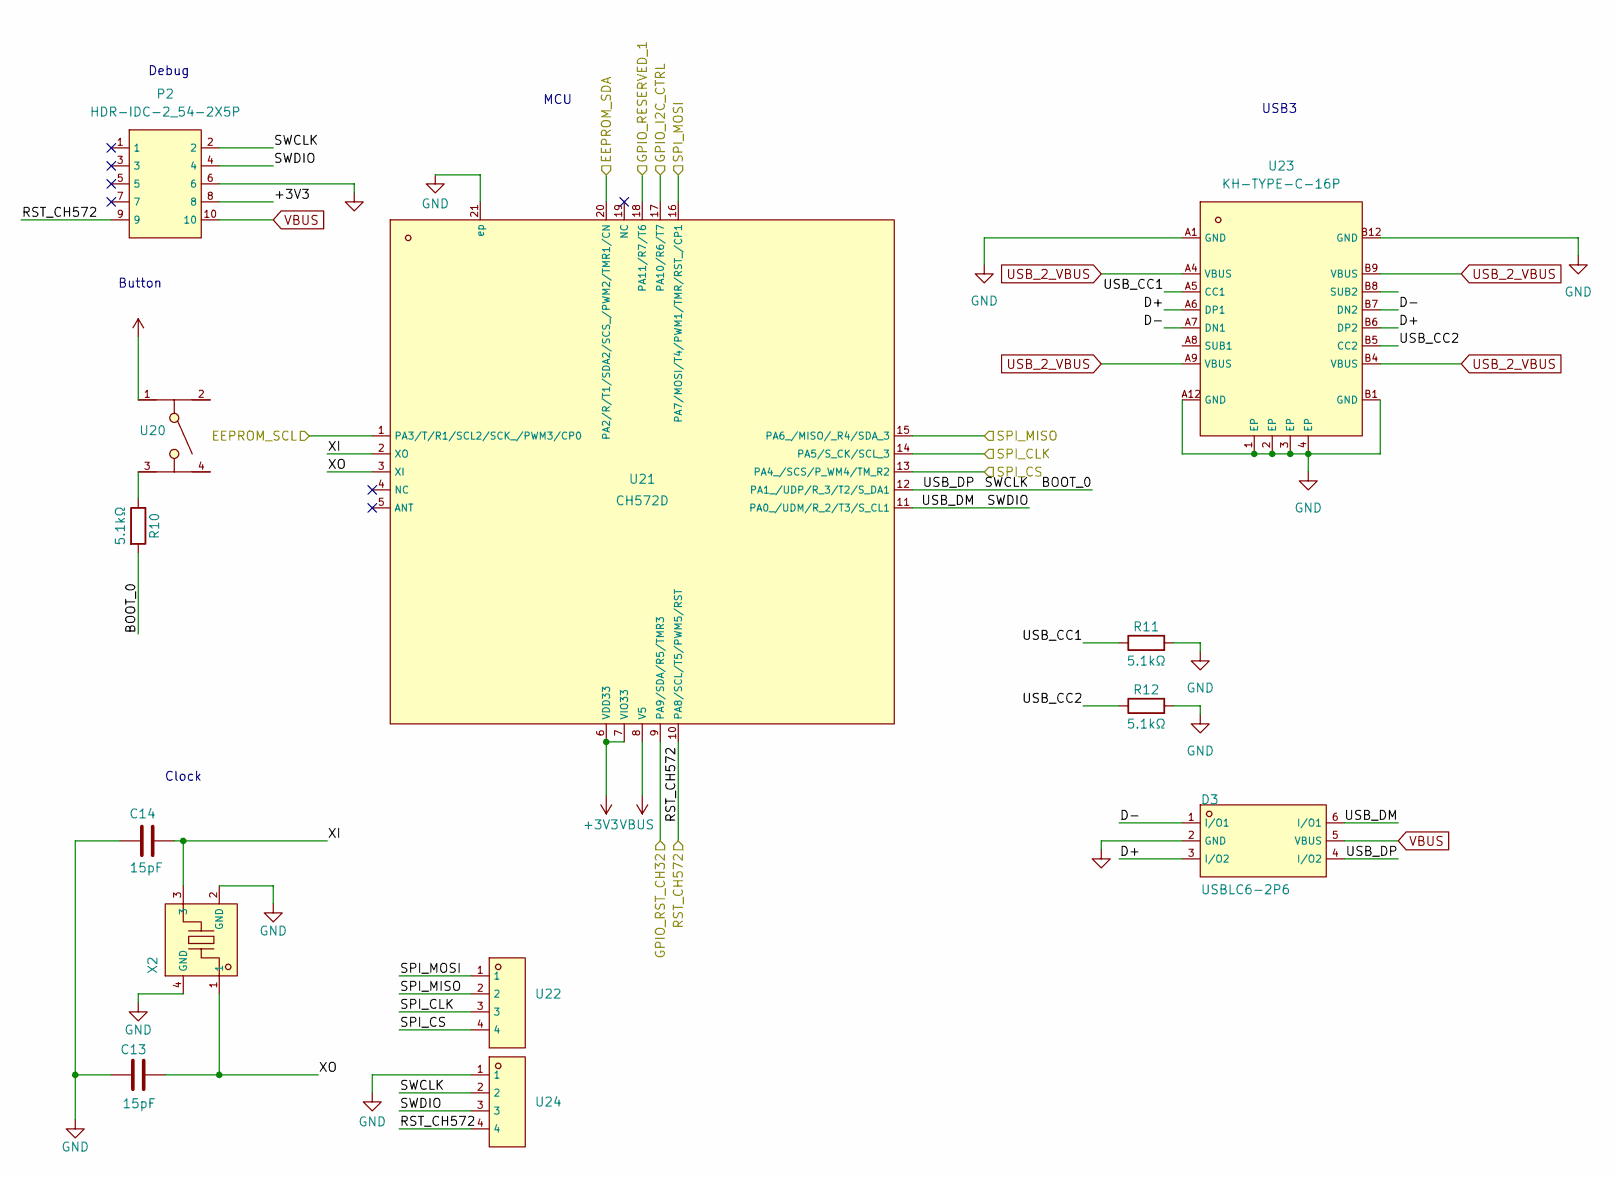
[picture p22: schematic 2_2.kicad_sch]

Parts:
C13, C14: 15pF; C_0402_1005Metric; Manufacturer Part 0402CG150J500NT; LCSC Part Name 15pF ±5% 50V
D3: USBLC6-2P6; SOT-666-6_L1.6-W1.2-P0.50-LS1.6-BL; Manufacturer Part USBLC6-2P6; LCSC Part Name MSL=3
P2: HDR-IDC-2_54-2X5P; IDC-TH_10P-P2.54_C5665; LCSC C5665
R10, R11, R12: 5.1kΩ; R_0603_1608Metric
U20: TC-6601-5_0-260-8_3; SW-SMD_4P-L6.0-W6.0-P4.50-LS8.2; Manufacturer Part TS-1088-AR02016; LCSC Part Name 4*3*2mm 立贴 轻触开关
U21: CH572D; QFN-20_L3.0-W3.0-P0.40-TL-EP1.7; LCSC C46597863
U22, U24: HX_PH254-01-04-Z-L11_5_STRAIGHT_PIN_HEADER; HDR-TH_4P-HX-PH254-01-04-Z-L11.5; LCSC C52016392
U23: KH-TYPE-C-16P; USB-C-SMD_KH-TYPE-C-16P; LCSC C709357
X2: XTM20032000DT00351001; CRYSTAL-SMD_4P-L2.0-W1.6-BL; LCSC C37635331

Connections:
+3V3: P2.8, U20.1, U21.6 (VDD33), U21.7 (VIO33); also elsewhere on the board
/CH32V203/EEPROM_SCL: U21.1 (PA3/T/R1/SCL2/SCK_/PWM3/CP0); also elsewhere on the board
/CH32V203/EEPROM_SDA: U21.20 (PA2/R/T1/SDA2/SCS_/PWM2/TMR1/CN); also elsewhere on the board
/CH32V203/GPIO_I2C_CTRL: U21.17 (PA10/R6/T7); also elsewhere on the board
/CH32V203/GPIO_RESERVED_1: U21.18 (PA11/R7/T6); also elsewhere on the board
/CH32V203/GPIO_RST_CH32: U21.9 (PA9/SDA/R5/TMR3); also elsewhere on the board
/CH32V203/RST: P2.9, U21.10 (PA8/SCL/T5/PWM5/RST), U24.4; also elsewhere on the board
/CH32V203/SPI_CLK: U21.14 (PA5/S_CK/SCL_3), U22.3; also elsewhere on the board
/CH32V203/SPI_CS: U21.13 (PA4_/SCS/P_WM4/TM_R2), U22.4; also elsewhere on the board
/CH32V203/SPI_MISO: U21.15 (PA6_/MISO/_R4/SDA_3), U22.2; also elsewhere on the board
/CH32V203/SPI_MOSI: U21.16 (PA7/MOSI/T4/PWM1/TMR/RST_/CP1), U22.1; also elsewhere on the board
/CH572D/BOOT_0: D3.4 (I/O2), P2.2, R10.2, U21.12 (PA1_/UDP/R_3/T2/S_DA1), U24.2
/CH572D/D+: D3.3 (I/O2), U23.A6 (DP1), U23.B6 (DP2)
/CH572D/D-: D3.1 (I/O1), U23.A7 (DN1), U23.B7 (DN2)
/CH572D/SWDIO: D3.6 (I/O1), P2.4, U21.11 (PA0_/UDM/R_2/T3/S_CL1), U24.3
/CH572D/USB_CC1: R11.1, U23.A5 (CC1)
/CH572D/USB_CC2: R12.1, U23.B5 (CC2)
/CH572D/XI: C14.1, U21.2 (XO), X2.3
/CH572D/XO: C13.2, U21.3 (XI), X2.1
GND: C13.1, C14.2, D3.2 (GND), P2.6, R11.2, R12.2, U21.21 (ep), U23.1 (EP), U23.2 (EP), U23.3 (EP), U23.4 (EP), U23.A1 (GND), U23.A12 (GND), U23.B1 (GND), U23.B12 (GND), U24.1, X2.2 (GND), X2.4 (GND); also elsewhere on the board
unnamed: R10.1, U20.3
USB_2_VBUS: U23.A4 (VBUS), U23.A9 (VBUS), U23.B4 (VBUS), U23.B9 (VBUS); also elsewhere on the board
VBUS: D3.5 (VBUS), P2.10, U21.8 (V5); also elsewhere on the board

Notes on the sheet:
USB3
Button
Debug
MCU
Clock

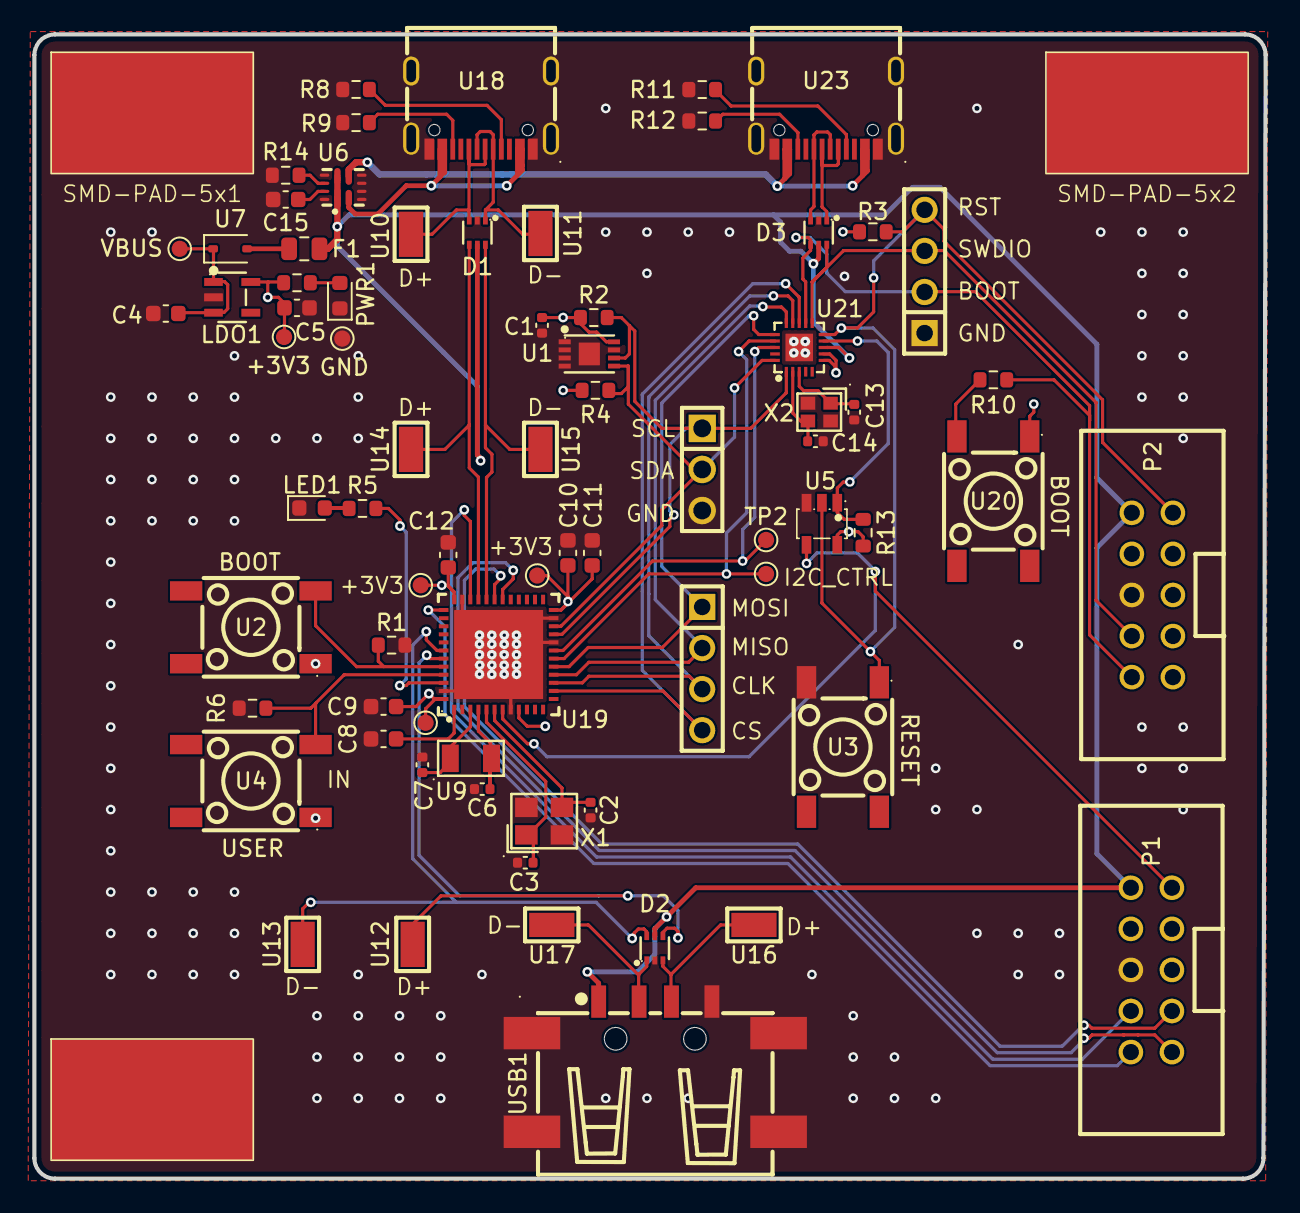
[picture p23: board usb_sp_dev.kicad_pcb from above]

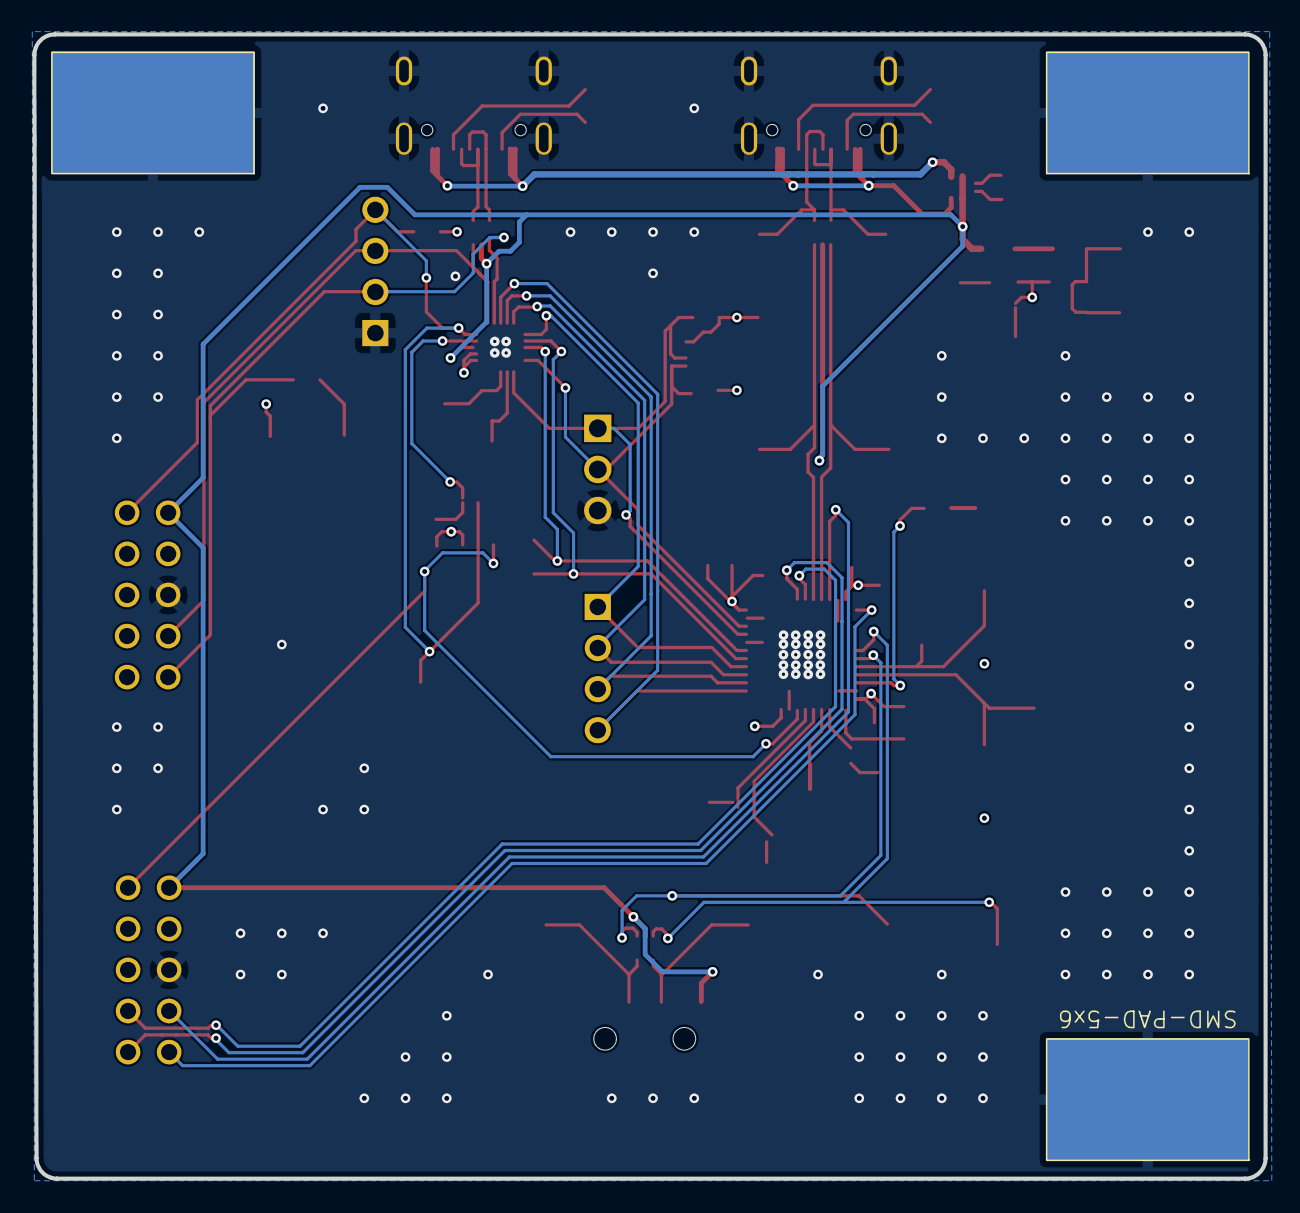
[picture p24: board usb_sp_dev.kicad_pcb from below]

Board: 4 copper layers, 76.1 x 70.7 mm, 79 parts (3 on the bottom side), 53 nets.

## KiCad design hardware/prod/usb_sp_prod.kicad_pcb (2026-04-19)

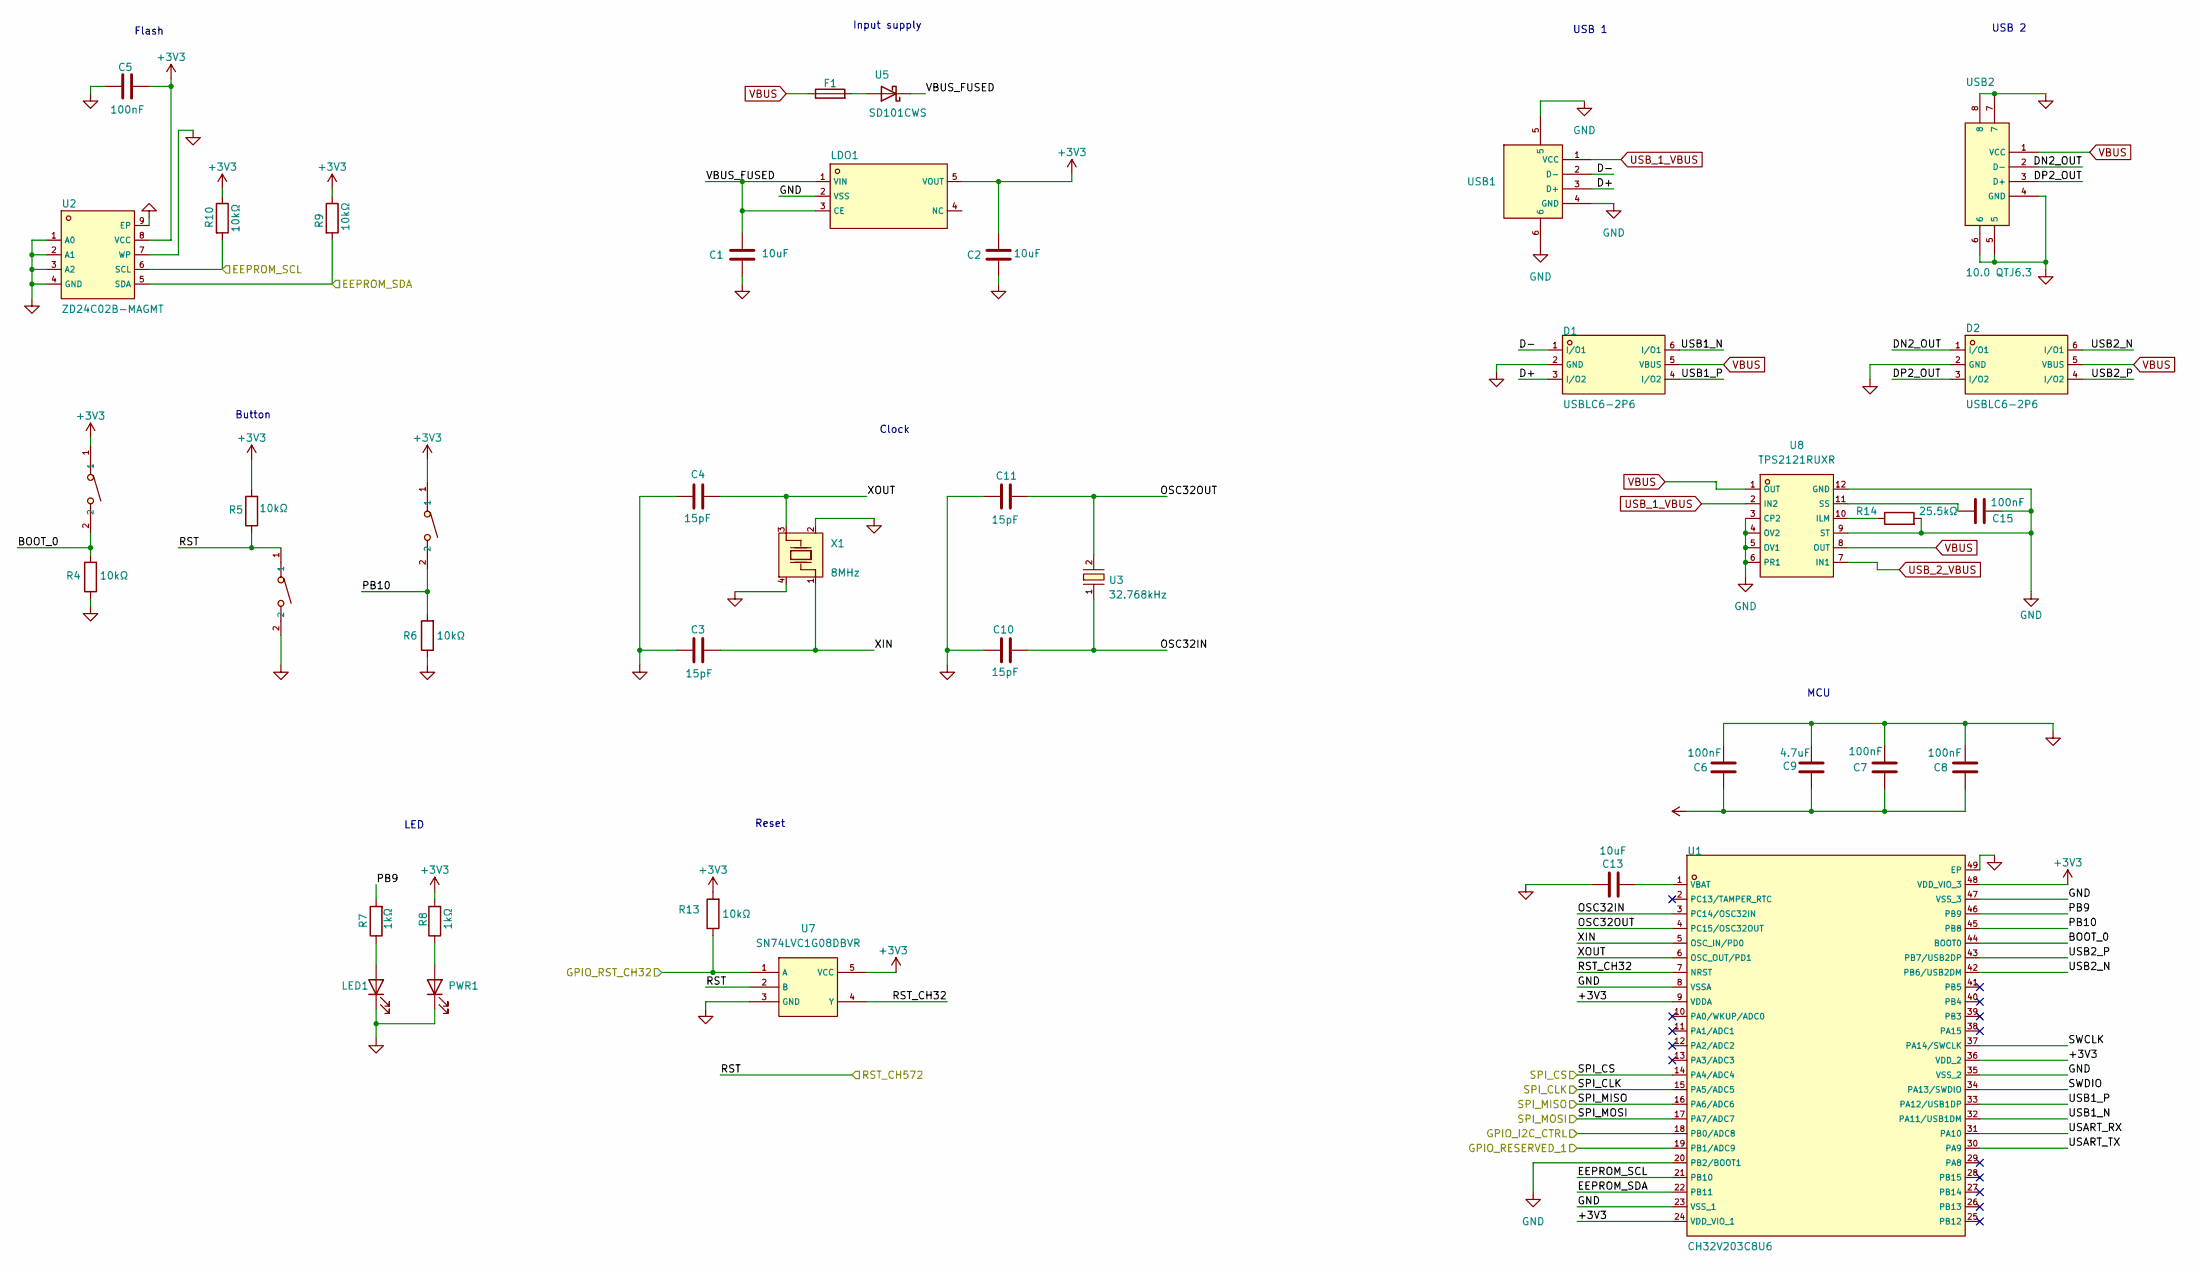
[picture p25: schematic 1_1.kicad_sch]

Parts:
C1, C2, C13: 10uF; C_0402_1005Metric; Voltage Rating 10V; Manufacturer Part CL05A106MP5NUNC; LCSC Part Name CAP CER 10uF 10V X5R 0402
C3, C4, C10, C11: 15pF; C_0402_1005Metric; Manufacturer Part 0402CG150J500NT; LCSC Part Name 15pF ±5% 50V
C5, C15: 100nF; C_0402_1005Metric; Manufacturer Part CL05B104KO5NNNC; LCSC Part Name 100nF ±10% 16V
C6, C7, C8: 100nF; C_0402_1005Metric; Manufacturer Part CC0402KRX7R7BB104; LCSC Part Name CAP CER 100nF 16V X7R 0402
C9: 4.7uF; C_0402_1005Metric; Manufacturer Part CL05A475KP5NRNC; LCSC Part Name 4.7uF ±10% 10V Ceramic Capacitor X5R 04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
D1, D2: USBLC6-2P6; SOT-666-6_L1.6-W1.2-P0.50-LS1.6-BL; Manufacturer Part USBLC6-2P6; LCSC Part Name MSL=3
F1: JK-SMD0805-020-30V; Fuse_0805_2012Metric; Manufacturer Part JK-SMD0805-020-30V; LCSC Part Name 30V 200mA 0805自恢复
LDO1: ME6211C33M5G-N; SOT-23-5_L3.0-W1.7-P0.95-LS2.8-BL; Manufacturer Part ME6211C33M5G-N; LCSC Part Name 输入6V 输出3.3V 500mA
LED1: XL-1608UGC-04; LED_0603_1608Metric; Manufacturer Part XL-1608UGC-04; LCSC Part Name XL-1608UGC-04
PWR1: NCD0603R1; LED_0603_1608Metric; Manufacturer Part NCD0603R1; LCSC Part Name NCD0603R1
R4, R5, R6, R9, R10, R13: 10kΩ; R_0402_1005Metric; Manufacturer Part RC0402FR-0710KL; LCSC Part Name RES 10kΩ ±1% 62.5mW 0402
R7, R8: 1kΩ; R_0402_1005Metric; Manufacturer Part 0402WGF1001TCE; LCSC Part Name 1kΩ ±1% 62.5mW 厚膜电阻
R14: 25.5kΩ; R_0402_1005Metric; Manufacturer Part RC0402FR-0710KL; LCSC Part Name RES 10kΩ ±1% 62.5mW 0402
RESET1, RESET2: SW-SMD_L3.9-W3.0-P4.45; Manufacturer Part TS-1088-AR02016; LCSC Part Name 4*3*2mm 立贴 轻触开关
U1: CH32V203C8U6; TQFN-48_L7.0-W7.0-P0.50-BL-EP5.5; Manufacturer Part CH32V203C8U6; LCSC Part Name CH32V203C8U6
U2: ZD24C02B-MAGMT; UDFN-8_L3.0-W2.0-P0.50-BL-EP-3; Manufacturer Part ZD24C02B-MAGMT; LCSC Part Name 2Kbit I2C兼容串行EEPROM
U3: 32.768kHz; CRYSTAL-SMD_L3.2-W1.5-1; Manufacturer Part H31003271C2070CY; LCSC Part Name 32.768kHz ±20ppm 12.5pF
U5: SD101CWS; D_SOD-323; Manufacturer Part SD101CWS; LCSC Part Name SD101CWS
U7: SN74LVC1G08DBVR; SOT-23-5_L3.0-W1.7-P0.95-LS2.8-BR; LCSC C7666
U8: TPS2121RUXR; VQFN-HR-12_L2.5-W2.0-P0.50-BL; LCSC C485916
USB1: USB-A-A/M_Stick_plate_bent_legs_VinylPBT_With_a_c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; USB-A-SMD_917-181A102ES60200; LCSC C46394
USB2: 10.0 QTJ6.3; USB-A-SMD_10.0-QTJ6.3; Manufacturer Part 10.0 QTJ6.3; LCSC Part Name Type-A 母 卧贴
USER1: SW-SMD_L3.9-W3.0-P4.45; Manufacturer Part TS-1088-AR02016; LCSC Part Name 4*3*2mm 立贴 轻触开关
X1: 8MHz; CRYSTAL-SMD_4P-L3.2-W2.5-BL; Manufacturer Part TAXM8M4RDBCCT2T; LCSC Part Name 8MHz ±10ppm 10pF

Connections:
+3V3: C2.2, C5.1, C6.1, C7.1, C8.1, C9.1, LDO1.5 (VOUT), R5.2, R8.2, R9.1, R10.1, R13.2, RESET2.1, U1.9 (VDDA), U1.24 (VDD_VIO_1), U1.36 (VDD_2), U1.48 (VDD_VIO_3), U2.8 (VCC), U7.5 (VCC), USER1.1; also elsewhere on the board
/CH32V203/BOOT_0: R4.2, RESET2.2, U1.44 (BOOT0)
/CH32V203/D+: D1.3 (I/O2), USB1.3 (D+)
/CH32V203/D-: D1.1 (I/O1), USB1.2 (D-)
/CH32V203/DN2_OUT: D2.1 (I/O1), USB2.2 (D-)
/CH32V203/DP2_OUT: D2.3 (I/O2), USB2.3 (D+)
/CH32V203/EEPROM_SCL: R10.2, U1.21 (PB10), U2.6 (SCL); also elsewhere on the board
/CH32V203/EEPROM_SDA: R9.2, U1.22 (PB11), U2.5 (SDA); also elsewhere on the board
/CH32V203/GPIO_I2C_CTRL: U1.18 (PB0/ADC8); also elsewhere on the board
/CH32V203/GPIO_RESERVED_1: U1.19 (PB1/ADC9); also elsewhere on the board
/CH32V203/GPIO_RST_CH32: R13.1, U7.1 (A); also elsewhere on the board
/CH32V203/OSC32IN: C10.2, U1.3 (PC14/OSC32IN), U3.1
/CH32V203/OSC32OUT: C11.1, U1.4 (PC15/OSC32OUT), U3.2
/CH32V203/PB9: R7.2, U1.46 (PB9)
/CH32V203/PB10: R6.2, U1.45 (PB8), USER1.2
/CH32V203/RST: R5.1, RESET1.1, U7.2 (B); also elsewhere on the board
/CH32V203/RST_CH32: U1.7 (NRST), U7.4 (Y)
/CH32V203/SPI_CLK: U1.15 (PA5/ADC5); also elsewhere on the board
/CH32V203/SPI_CS: U1.14 (PA4/ADC4); also elsewhere on the board
/CH32V203/SPI_MISO: U1.16 (PA6/ADC6); also elsewhere on the board
/CH32V203/SPI_MOSI: U1.17 (PA7/ADC7); also elsewhere on the board
/CH32V203/SWCLK: U1.37 (PA14/SWCLK); also elsewhere on the board
/CH32V203/SWDIO: U1.34 (PA13/SWDIO); also elsewhere on the board
/CH32V203/USART_RX: U1.31 (PA10)
/CH32V203/USART_TX: U1.30 (PA9)
/CH32V203/USB1_N: D1.6 (I/O1), U1.32 (PA11/USB1DM)
/CH32V203/USB1_P: D1.4 (I/O2), U1.33 (PA12/USB1DP)
/CH32V203/USB2_N: D2.6 (I/O1), U1.42 (PB6/USB2DM)
/CH32V203/USB2_P: D2.4 (I/O2), U1.43 (PB7/USB2DP)
/CH32V203/VBUS_FUSED: C1.2, LDO1.1 (VIN), LDO1.3 (CE), U5.1 (K)
/CH32V203/XIN: C3.2, U1.5 (OSC_IN/PD0), X1.1
/CH32V203/XOUT: C4.1, U1.6 (OSC_OUT/PD1), X1.3
GND: C1.1, C2.1, C3.1, C4.2, C5.2, C6.2, C7.2, C8.2, C9.2, C10.1, C11.2, C13.2, C15.2, D1.2 (GND), D2.2 (GND), LDO1.2 (VSS), LED1.1 (K), PWR1.1 (K), R4.1, R6.1, R14.2, RESET1.2, U1.8 (VSSA), U1.20 (PB2/BOOT1), U1.23 (VSS_1), U1.35 (VSS_2), U1.47 (VSS_3), U1.49 (EP), U2.1 (A0), U2.2 (A1), U2.3 (A2), U2.4 (GND), U2.7 (WP), U2.9 (EP), U7.3 (GND), U8.3 (CP2), U8.4 (OV2), U8.5 (OV1), U8.6 (PR1), U8.9 (ST), U8.12 (GND), USB1.4 (GND), USB1.5, USB1.6, USB2.4 (GND), USB2.5, USB2.6, USB2.7, USB2.8, X1.2, X1.4; also elsewhere on the board
unnamed: LED1.2 (A), R7.1
unnamed: PWR1.2 (A), R8.1
unnamed: C13.1, U1.1 (VBAT)
unnamed: F1.2, U5.2 (A)
unnamed: R14.1, U8.10 (ILM)
unnamed: C15.1, U8.11 (SS)
USB_1_VBUS: U8.2 (IN2), USB1.1 (VCC)
USB_2_VBUS: U8.7 (IN1); also elsewhere on the board
VBUS: D1.5 (VBUS), D2.5 (VBUS), F1.1, U8.1 (OUT), U8.8 (OUT), USB2.1 (VCC)

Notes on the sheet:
Reset
Clock
Button
Flash
Input supply
USB 1
USB 2
LED
MCU

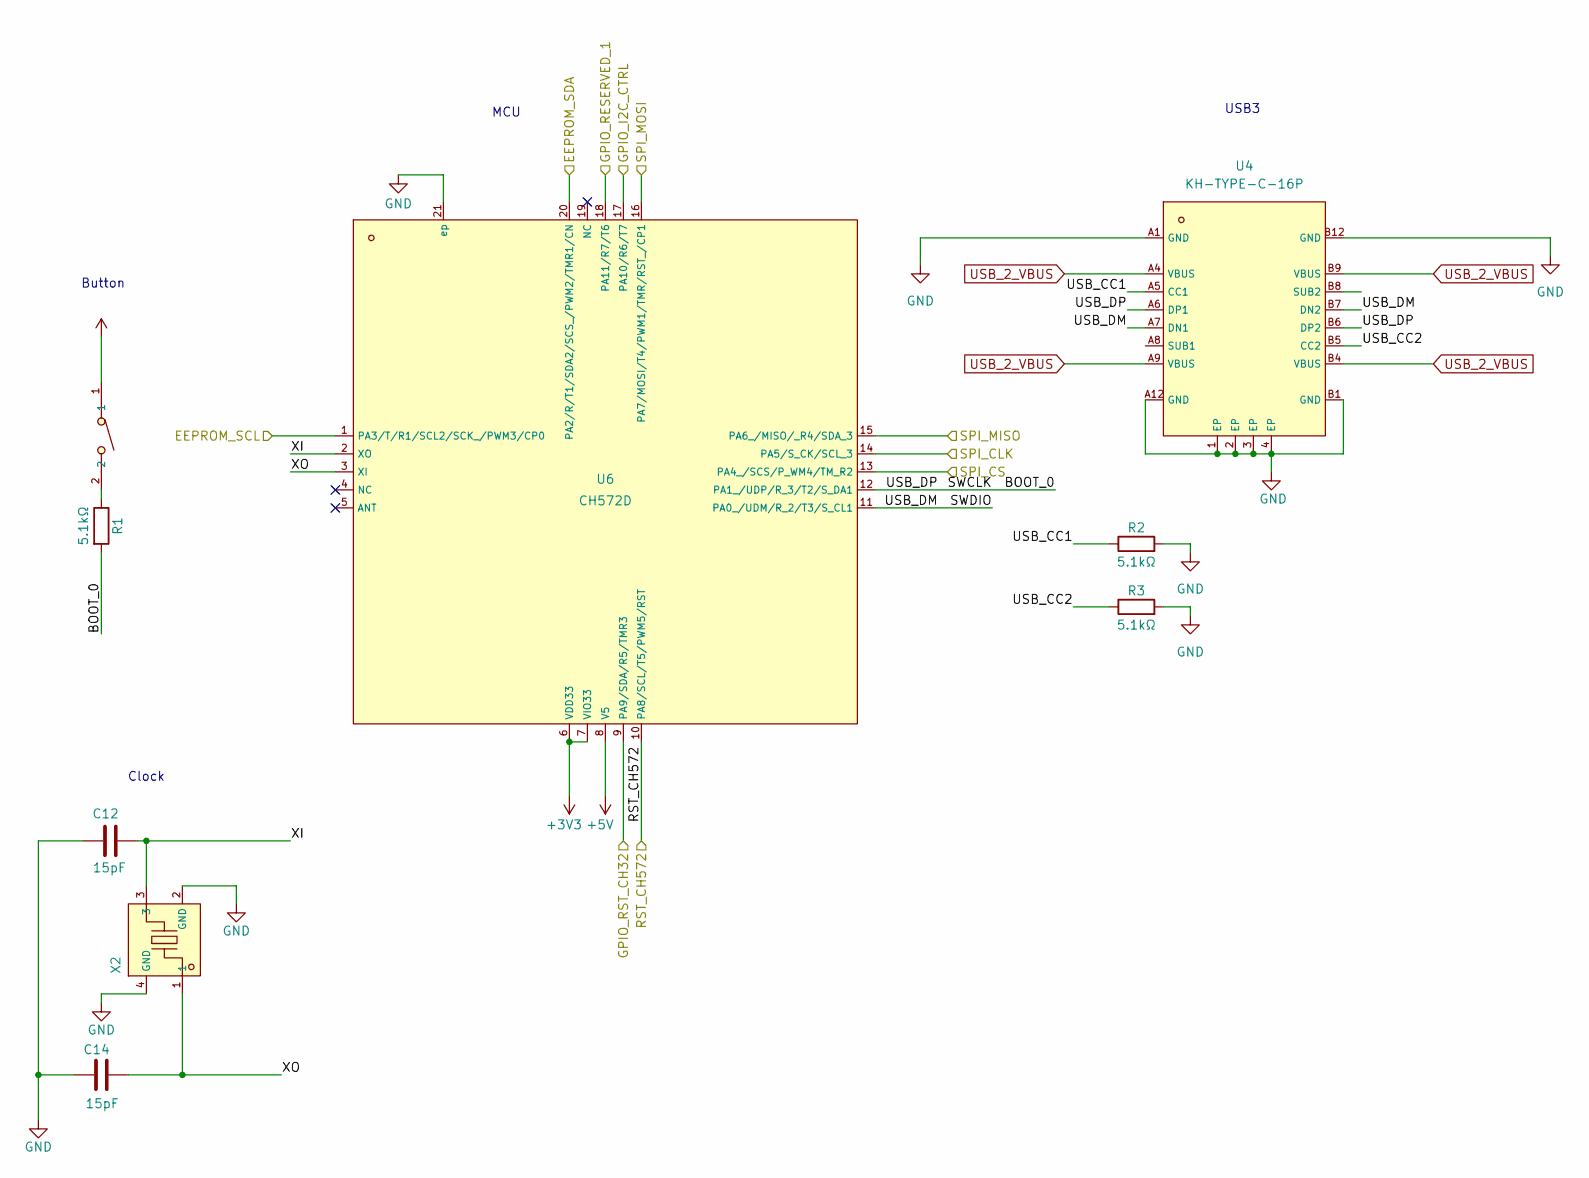
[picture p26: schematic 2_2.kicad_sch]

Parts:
BOOT_1: SW-SMD_L3.9-W3.0-P4.45; Manufacturer Part TS-1088-AR02016; LCSC Part Name 4*3*2mm 立贴 轻触开关
C12, C14: 15pF; C_0402_1005Metric; Manufacturer Part 0402CG150J500NT; LCSC Part Name 15pF ±5% 50V
R1, R2, R3: 5.1kΩ; R_0402_1005Metric
U4: KH-TYPE-C-16P; USB-C-SMD_KH-TYPE-C-16P; LCSC C709357
U6: CH572D; QFN-20_L3.0-W3.0-P0.40-TL-EP1.7; LCSC C46597863
X2: XTM20032000DT00351001; CRYSTAL-SMD_4P-L2.0-W1.6-BL; LCSC C37635331

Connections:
+3V3: BOOT_1.1, U6.6 (VDD33), U6.7 (VIO33); also elsewhere on the board
+5V: U6.8 (V5)
/CH32V203/EEPROM_SCL: U6.1 (PA3/T/R1/SCL2/SCK_/PWM3/CP0); also elsewhere on the board
/CH32V203/EEPROM_SDA: U6.20 (PA2/R/T1/SDA2/SCS_/PWM2/TMR1/CN); also elsewhere on the board
/CH32V203/GPIO_I2C_CTRL: U6.17 (PA10/R6/T7); also elsewhere on the board
/CH32V203/GPIO_RESERVED_1: U6.18 (PA11/R7/T6); also elsewhere on the board
/CH32V203/GPIO_RST_CH32: U6.9 (PA9/SDA/R5/TMR3); also elsewhere on the board
/CH32V203/RST: U6.10 (PA8/SCL/T5/PWM5/RST); also elsewhere on the board
/CH32V203/SPI_CLK: U6.14 (PA5/S_CK/SCL_3); also elsewhere on the board
/CH32V203/SPI_CS: U6.13 (PA4_/SCS/P_WM4/TM_R2); also elsewhere on the board
/CH32V203/SPI_MISO: U6.15 (PA6_/MISO/_R4/SDA_3); also elsewhere on the board
/CH32V203/SPI_MOSI: U6.16 (PA7/MOSI/T4/PWM1/TMR/RST_/CP1); also elsewhere on the board
/CH572D/BOOT_0: R1.2, U4.A6 (DP1), U4.B6 (DP2), U6.12 (PA1_/UDP/R_3/T2/S_DA1)
/CH572D/SWDIO: U4.A7 (DN1), U4.B7 (DN2), U6.11 (PA0_/UDM/R_2/T3/S_CL1)
/CH572D/USB_CC1: R2.1, U4.A5 (CC1)
/CH572D/USB_CC2: R3.1, U4.B5 (CC2)
/CH572D/XI: C12.1, U6.2 (XO), X2.3
/CH572D/XO: C14.2, U6.3 (XI), X2.1
GND: C12.2, C14.1, R2.2, R3.2, U4.1 (EP), U4.2 (EP), U4.3 (EP), U4.4 (EP), U4.A1 (GND), U4.A12 (GND), U4.B1 (GND), U4.B12 (GND), U6.21 (ep), X2.2 (GND), X2.4 (GND); also elsewhere on the board
unnamed: BOOT_1.2, R1.1
USB_2_VBUS: U4.A4 (VBUS), U4.A9 (VBUS), U4.B4 (VBUS), U4.B9 (VBUS); also elsewhere on the board

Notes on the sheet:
USB3
Button
MCU
Clock

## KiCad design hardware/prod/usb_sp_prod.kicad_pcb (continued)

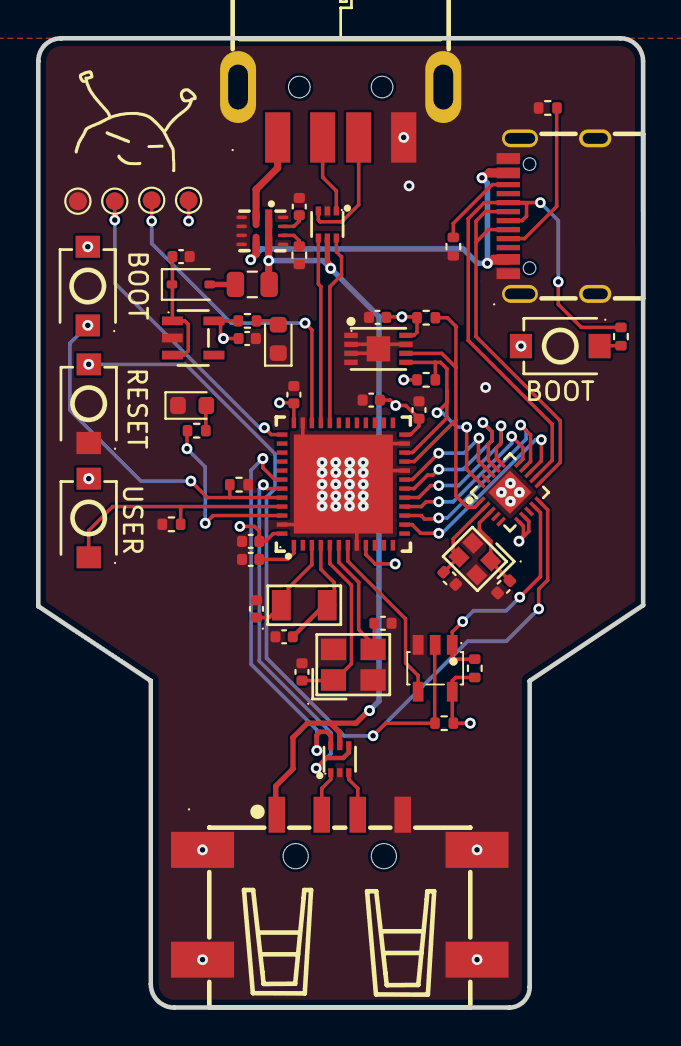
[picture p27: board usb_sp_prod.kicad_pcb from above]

Board: 4 copper layers, 33.6 x 53.9 mm, 53 parts (0 on the bottom side), 47 nets.

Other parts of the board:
TP1, TP2, TP3, TP4: TestPoint; TestPoint_Pad_D1.0mm

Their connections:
+3V3: TP3.1 (1_1); also elsewhere on the board
/CH32V203/SWCLK: TP1.1 (1_1); also elsewhere on the board
/CH32V203/SWDIO: TP2.1 (1_1); also elsewhere on the board
GND: TP4.1 (1_1); also elsewhere on the board

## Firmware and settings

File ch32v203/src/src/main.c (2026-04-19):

#include "debug.h"
#include "debug_log.h"
#include "usb_lib.h"
#include "usbd.h"
#include "usbh.h"
#include "relay.h"
#include "queue.h"
#include "user.h"
#include "app.h"
#include "eeprom.h"
#include "spi_link.h"
#include <stdbool.h>
#include <string.h>

static void handle_device_disconnection(void);
static uint8_t handle_device_connection(void);
static uint8_t handle_endpoint_transfer(void);
static uint8_t reenum_requested = 0;

typedef struct
{
    uint8_t valid;
    uint16_t len;
    uint8_t buf[MAX_PKT_SZ];
} relay_in_slot_t;

static relay_in_slot_t relay_in_slots[MAX_EP_NUM];

static void stop_relay_communication(void)
{

    usb_hw_set_port(DISABLE, DISABLE);
    bDeviceState = UNCONNECTED;

    isr_out_pending = 0;
    memset(isr_out_queue, 0, sizeof(isr_out_queue));
    memset(Host_OutBusy, 0, sizeof(Host_OutBusy));
    memset(Host_OutToggle, 0, sizeof(Host_OutToggle));
    memset(Host_InBusy, 0, sizeof(Host_InBusy));
    memset(Host_InToggle, 0, sizeof(Host_InToggle));
    memset(relay_in_slots, 0, sizeof(relay_in_slots));
}

static void print_banner(void)
{
    LOG_INFO("--------------------------------------------------------");
    LOG_INFO("                      USBsp v0.1.0                      ");
    LOG_INFO("--------------------------------------------------------");
}

static void log_reset_cause(uint32_t rstsckr_snapshot)
{
    bool matched = false;

    LOG_INFO("reset flags (rstsckr): 0x%08lX", (unsigned long)rstsckr_snapshot);

    if ((rstsckr_snapshot & RCC_PORRSTF) != 0U)
    {
        LOG_INFO("reset cause: POR/PDR (power reset)");
        matched = true;
    }
    if ((rstsckr_snapshot & RCC_PINRSTF) != 0U)
    {
        LOG_INFO("reset cause: NRST pin");
        matched = true;
    }
    if ((rstsckr_snapshot & RCC_SFTRSTF) != 0U)
    {
        LOG_INFO("reset cause: software reset");
        matched = true;
    }
    if ((rstsckr_snapshot & RCC_IWDGRSTF) != 0U)
    {
        LOG_INFO("reset cause: IWDG watchdog");
        matched = true;
    }
    if ((rstsckr_snapshot & RCC_WWDGRSTF) != 0U)
    {
        LOG_INFO("reset cause: WWDG watchdog");
        matched = true;
    }
    if ((rstsckr_snapshot & RCC_LPWRRSTF) != 0U)
    {
        LOG_INFO("reset cause: low-power reset");
        matched = true;
    }

    if (!matched)
    {
        LOG_INFO("reset cause: unknown (no reset flags set)");
    }
}

/* Initialize USB clock */
static uint8_t init_usb_clock(void)
{
    LOG_INFO("usb: Configuring USB clock, sysclock: %ld", SystemCoreClock);
    usbd_hw_set_clk();
    usbh_hw_set_clk();
    return ERR_SUCCESS;
}

/* Initialize USB host driver */
static uint8_t init_usb_host(void)
{
    LOG_INFO("usbh: Initializing USB host driver");
    usbh_init(ENABLE);
    return ERR_SUCCESS;
}

/* Configure USB interrupts */
static uint8_t init_usb_interrupts(void)
{
    LOG_INFO("usbd: Configuring USB interrupts");
    usb_hw_set_isr_config();
    return ERR_SUCCESS;
}

/* Initialize user peripherals */
static uint8_t init_peripherals(void)
{
    LOG_INFO("sys: enabling the USER button");
    user_btn_init();
    LOG_INFO("sys: enabling the USER LED");
    user_led_init();
    LOG_INFO("sys: reading EEPROM");
    AT24C02_init();
    AT24C02_read_usb_info();
    return ERR_SUCCESS;
}

/* Initialize system components */
static uint8_t init_system(void)
{
    uint32_t reset_flags = RCC->RSTSCKR;

    NVIC_PriorityGroupConfig(NVIC_PriorityGroup_1);
    Delay_Init();
    USART_Debug_Init(115200);
    tim2_init((SystemCoreClock / 100) - 1);

    print_banner();
    LOG_INFO("systemclk: %ld", SystemCoreClock);
    log_reset_cause(reset_flags);
    RCC_ClearFlag();

    uint8_t status;
    if ((status = init_usb_clock()) != ERR_SUCCESS) return status;
    if ((status = init_usb_host()) != ERR_SUCCESS) return status;
    if ((status = init_usb_interrupts()) != ERR_SUCCESS) return status;
    if ((status = init_peripherals()) != ERR_SUCCESS) return status;
    spi_link_init();
    user_clear_connected_usb_snapshot();

    memset(&RootHubDev, 0, sizeof(ROOT_HUB_DEVICE));
    memset(&HostCtl[DEF_USBFS_PORT_INDEX * DEF_ONE_USB_SUP_DEV_TOTAL], 0,
           DEF_ONE_USB_SUP_DEV_TOTAL * sizeof(HOST_CTL));
    return ERR_SUCCESS;
}

/* Log device type based on class */
static void log_device_type(uint8_t device_type)
{
    switch (device_type)
    {
        case USB_DEV_CLASS_HID:      LOG_INFO("usbh: root device is HID"); break;
        case USB_DEV_CLASS_STORAGE:  LOG_INFO("usbh: root device is storage"); break;
        case USB_DEV_CLASS_PRINTER:  LOG_INFO("usbh: root device is printer"); break;
        case USB_DEV_CLASS_VEN_SPEC: LOG_INFO("usbh: root device is vendor specific"); break;
        case USB_DEV_CLASS_HUB:      LOG_INFO("usbh: root device is hub"); break;
        default:                     LOG_INFO("usbh: root device class %d", device_type); break;
    }
}

/* Handle USB device connection */
static uint8_t handle_device_connection(void)
{
    const uint8_t index = DEF_USBFS_PORT_INDEX * DEF_ONE_USB_SUP_DEV_TOTAL;

    uint8_t status = usbh_enumerate_root_device();
    if (status == ERR_USB_DISCON)
    {
        LOG_WARN("usbh: device disconnected during enumeration");
        handle_device_disconnection();
        return status;
    }
    if (status != ERR_SUCCESS)
    {
        LOG_ERROR("usbh: enumeration failed with error code %x", status);
        RootHubDev.bStatus = ROOT_DEV_FAILED;
        return status;
    }

    LOG_DEBUG("usbh: success, device type %d", RootHubDev.bType);
    log_device_type(RootHubDev.bType);

    LOG_INFO("usb: Initializing USB driver");
    app_analyze_config_descriptor(index, RootHubDev.bEp0MaxPks);
    LOG_INFO("usb: Max packet size: %d", RootHubDev.bEp0MaxPks);

    usbh_get_string_descriptors(RootHubDev.bEp0MaxPks);
    eeprom_apply_usb_overrides();
    stop_relay_communication();

    if (eeprom_usb_info.has_attach_delay_ms && eeprom_usb_info.attach_delay_ms != 0u)
    {
        LOG_INFO("usb: delaying upstream attach by %u ms", eeprom_usb_info.attach_delay_ms);
        Delay_Ms(eeprom_usb_info.attach_delay_ms);
    }

    if ((eeprom_usb_info.has_flags == 0u) || ((eeprom_usb_info.flags & EEPROM_FLAG_BOOT_CONNECTED) != 0u))
    {
        usb_relay_driver_init();
        LOG_INFO("usb: Relay side initialized");
    }
    else
    {
        LOG_INFO("usb: Relay kept disconnected by EEPROM bootConnected=0");
    }

    LOG_DEBUG("number of interfaces: %d", HostCtl[index].InterfaceNum);
    RootHubDev.bStatus = ROOT_DEV_SUCCESS;
    reenum_requested = 0u;
    return ERR_SUCCESS;
}

/* Handle USB device disconnection */
static void handle_device_disconnection(void)
{
    const uint8_t device_index = DEF_USBFS_PORT_INDEX * DEF_ONE_USB_SUP_DEV_TOTAL;

    stop_relay_communication();
    memset(&HostCtl[device_index], 0, sizeof(HOST_CTL));
    memset(&RootHubDev, 0, sizeof(ROOT_HUB_DEVICE));
    user_clear_connected_usb_snapshot();
    reenum_requested = 0u;

    LOG_INFO("usb: port dev out");
    LOG_INFO("usb: relay stopped; waiting for a new device connection");
}

/* Handle endpoint TX transfer */
static uint8_t handle_endpoint_tx(uint8_t index, uint8_t ep_out, uint8_t ep_type, uint8_t *temp_buf, uint16_t *len)
{
    uint8_t tx_status = ERR_USB_TRANSFER;
    uint8_t sent_any = 0;
    uint8_t has_space = 0u;

    if (index >= DEF_ONE_USB_SUP_DEV_TOTAL)
    {
        LOG_ERROR("usb: invalid index %d or endpoint %d", index, ep_out);
        return ERR_USB_UNKNOWN;
    }
    if (ep_out == 0)
    {
        return ERR_SUCCESS;
    }
    if (ep_out >= MAX_EP_NUM)
    {
        return ERR_SUCCESS;
    }
    if (temp_buf == NULL || len == NULL)
    {
        LOG_ERROR("usb: null buffer or length pointer");
        return ERR_USB_UNKNOWN;
    }

    if (Host_OutBusy[ep_out])
    {
        return ERR_USB_TRANSFER;
    }

    while (peek_packet_for_main(ep_out, temp_buf, len) == 0)
    {
        LOG_DEBUG("usb: ep%u TX dequeue len=%u depth_before=%u pending=%u", ep_out,
                  (unsigned)*len, (unsigned)isr_out_queue[ep_out].count,
                  (unsigned)isr_out_pending);

        Host_OutBusy[ep_out] = 1;
        tx_status = USBFSH_SendEndpData(ep_out, &Host_OutToggle[ep_out], temp_buf, *len);
        Host_OutBusy[ep_out] = 0;

        LOG_DEBUG("usb: ep%u TX status=0x%02X", ep_out, tx_status);

        if (tx_status == ERR_SUCCESS)
        {
            spi_link_capture_packet(0u, ep_out, ep_type, temp_buf, *len);
            has_space = 0u;
            (void)pop_packet_for_main_and_check_space(ep_out, &has_space);
            LOG_DEBUG("usb: ep%u TX pop depth_after=%u pending=%u", ep_out,
                      (unsigned)isr_out_queue[ep_out].count, (unsigned)isr_out_pending);

            if (has_space != 0u)
            {
                SetEPRxStatus(ep_out, EP_RX_VALID);
                LOG_DEBUG("usb: ep%u RX->VALID (space available depth=%u)", ep_out,
                          (unsigned)isr_out_queue[ep_out].count);
            }
            else
            {
                SetEPRxStatus(ep_out, EP_RX_NAK);
                LOG_DEBUG("usb: ep%u RX->NAK (queue full depth=%u)", ep_out,
                          (unsigned)isr_out_queue[ep_out].count);
            }
            sent_any = 1;
            continue;
        }

        if (tx_status == ERR_USB_DISCON)
        {
            LOG_INFO("usbh: device disconnected from host port");
                handle_device_disconnection();
                return tx_status;
        }

        if (tx_status == (USB_PID_STALL | ERR_USB_TRANSFER))
        {
            LOG_WARN("usbh: host OUT endpoint %u stalled, clearing halt", ep_out);
            (void)USBFSH_ClearEndpStall(RootHubDev.bEp0MaxPks, ep_out);
            Host_OutToggle[ep_out] = 0x00;
        }
        else if (tx_status != (USB_PID_NAK | ERR_USB_TRANSFER))
        {
            LOG_DEBUG("usbh: host OUT endpoint %u tx error %u", ep_out, tx_status);
        }
        break;
    }

    if (sent_any) return ERR_SUCCESS;
    return tx_status;
}

/* Handle endpoint RX transfer */
static uint8_t handle_endpoint_rx(uint8_t index, uint8_t intf_num, uint8_t ep_num, uint8_t ep_addr, uint8_t ep_type)
{
    relay_in_slot_t *slot;
    uint8_t status;

    if (index >= DEF_ONE_USB_SUP_DEV_TOTAL || intf_num >= HostCtl[index].InterfaceNum)
    {
        LOG_ERROR("usb: invalid index %d or interface %d", index, intf_num);
        return ERR_USB_UNKNOWN;
    }
    slot = &relay_in_slots[ep_addr];

    if (slot->valid != 0u)
    {
        if (bDeviceState == CONFIGURED && _GetEPTxStatus(ep_addr) == EP_TX_NAK &&
            UDBD_ENDP_Busy(ep_addr) == 0)
        {
            status = USBD_ENDP_DataUp(ep_addr, slot->buf, slot->len);
            if (status == ERR_SUCCESS)
            {
                slot->valid = 0u;
            }
            return status;
        }

        return ERR_USB_TRANSFER;
    }

    status = USBFSH_GetEndpData(ep_addr,
        &HostCtl[index].Interface[intf_num].InEndpTog[ep_num], Com_Buf, &Com_Buf_Len);
    
    if (status == ERR_SUCCESS)
    {
        if (Com_Buf == NULL || Com_Buf_Len > MAX_PKT_SZ)
        {
            HostCtl[index].Interface[intf_num].InEndpTog[ep_num] = 0x00;
            return ERR_USB_TRANSFER;
        }
        spi_link_capture_packet(1u, ep_addr, ep_type, Com_Buf, Com_Buf_Len);

        slot->len = Com_Buf_Len;
        if (Com_Buf_Len != 0u)
        {
            memcpy(slot->buf, Com_Buf, Com_Buf_Len);
        }
        slot->valid = 1u;

        if (bDeviceState == CONFIGURED && _GetEPTxStatus(ep_addr) == EP_TX_NAK &&
            UDBD_ENDP_Busy(ep_addr) == 0)
        {
            status = USBD_ENDP_DataUp(ep_addr, slot->buf, slot->len);
            if (status == ERR_SUCCESS)
            {
                slot->valid = 0u;
            }
        }
    } else if (status == ERR_USB_DISCON)
    {
        LOG_INFO("usbh: device disconnected from host port");
        handle_device_disconnection();
    } else if (status == (USB_PID_STALL | ERR_USB_TRANSFER))
    {
        LOG_ERROR("usbh: abnormal event on host port endpoint %d", ep_addr);
        USBFSH_ClearEndpStall(RootHubDev.bEp0MaxPks, ep_addr | 0x80);
        HostCtl[index].Interface[intf_num].InEndpTog[ep_num] = 0x00;
        HostCtl[index].ErrorCount++;
        if (HostCtl[index].ErrorCount >= 20)
        {
            LOG_INFO("usbh: too many errors, scheduling re-enumeration");
            reenum_requested = 1u;
            HostCtl[index].ErrorCount = 0;
        }
    }
    return status;
}

/* Handle endpoint transfers for all interfaces and endpoints */
static uint8_t handle_endpoint_transfer(void)
{
    const uint8_t index = DEF_USBFS_PORT_INDEX * DEF_ONE_USB_SUP_DEV_TOTAL;

    uint8_t temp_buf[MAX_PKT_SZ];
    uint16_t len;

    for (uint8_t intf_num = 0; intf_num < HostCtl[index].InterfaceNum; intf_num++)
    {
        uint8_t out_endp_num = HostCtl[index].Interface[intf_num].OutEndpNum;
        uint8_t in_endp_num = HostCtl[index].Interface[intf_num].InEndpNum;

        for (uint8_t ep_num = 0; ep_num < out_endp_num; ep_num++)
        {
            uint8_t ep_out = HostCtl[index].Interface[intf_num].OutEndpAddr[ep_num];
            uint8_t ep_type = HostCtl[index].Interface[intf_num].OutEndpType[ep_num] & 0x03u;
            uint8_t tx_status = handle_endpoint_tx(index, ep_out, ep_type, temp_buf, &len);
            if (tx_status == ERR_USB_DISCON)
            {
                return tx_status;
            }
        }

        for (uint8_t ep_num = 0; ep_num < in_endp_num; ep_num++)
        {
            uint8_t ep_addr = HostCtl[index].Interface[intf_num].InEndpAddr[ep_num];
            uint8_t ep_type = HostCtl[index].Interface[intf_num].InEndpType[ep_num] & 0x03u;
            uint32_t last_poll = HostCtl[index].Interface[intf_num].LastInPollTime[ep_num];
            uint32_t interval  = HostCtl[index].Interface[intf_num].InEndpInterval[ep_num];

            uint32_t current_time = bIntPackSOF;
            uint8_t should_poll = 0u;

            /* Bulk/control IN endpoints should be serviced as fast as possible. */
            if ((ep_type == 0x02u) || (ep_type == 0x00u))
            {
                should_poll = 1u;
            }
            else
            {
                if (interval == 0u)
                {
                    interval = 1u;
                }
                if ((current_time - last_poll) >= interval)
                {
                    should_poll = 1u;
                }
            }

            if (should_poll)
            {
                uint8_t rx_status;

                HostCtl[index].Interface[intf_num].LastInPollTime[ep_num] = current_time;
                /* Handle RX transfer */
                rx_status = handle_endpoint_rx(index, intf_num, ep_num, ep_addr, ep_type);
                if (rx_status == ERR_USB_DISCON) {
                    return rx_status;
                }
            }
            /* Set TX status if endpoint is not busy */
            if (UDBD_ENDP_Busy(ep_addr) == 0)
            {
                SetEPTxStatus(ep_addr, EP_TX_NAK);
            }
        }
    }

    return ERR_SUCCESS;
}

/* Main program loop */
int main(void)
{
    if (init_system() != ERR_SUCCESS)
    {
        LOG_ERROR("sys: system initialization failed");
        while (1); /* Halt on failure */
    }

    while (1)
    {
        uint8_t status = USBFSH_CheckRootHubPortStatus(RootHubDev.bStatus);

        if (status == ROOT_DEV_CONNECTED)
        {
            LOG_INFO("usb: port dev in");
            RootHubDev.bStatus = ROOT_DEV_CONNECTED;
            RootHubDev.DeviceIndex = DEF_USBFS_PORT_INDEX * DEF_ONE_USB_SUP_DEV_TOTAL;
            handle_device_connection();
        } else if (status == ROOT_DEV_DISCONNECT)
        {
            handle_device_disconnection();
        }

        if ((reenum_requested != 0u) && (RootHubDev.bStatus >= ROOT_DEV_SUCCESS))
        {
            (void)handle_device_connection();
        }

        if (RootHubDev.bStatus >= ROOT_DEV_SUCCESS && bDeviceState == CONFIGURED)
        {
            uint8_t relay_status = usb_relay_poll();
            if (relay_status == ERR_USB_DISCON)
            {
                handle_device_disconnection();
                continue;
            }
            (void)handle_endpoint_transfer();
        }

        spi_link_task();

        if (user_reset_requested() != 0u)
        {
            user_clear_reset_request();
            LOG_INFO("system: resetting now");
            NVIC_SystemReset();
        }
    }
}

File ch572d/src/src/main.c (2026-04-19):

#include "CH57x_common.h"
#include "log.h"
#include "usb/usb_cdc.h"
#include "eeprom/eeprom.h"
#include "usb/usb_logs.h"
#include "spi_link.h"

__HIGH_CODE
int main(void)
{
    R16_PIN_ALTERNATE &= ~RB_PIN_DEBUG_EN;
    HSECFG_Capacitance(HSECap_18p);
    SetSysClock(CLK_SOURCE_HSE_PLL_100MHz);
    AT24C02_bus_release();

    usb_cdc_init();
    log_printf("USB CDC ready\r\n");

    spi_link_init();

    while (1) {
        usb_cdc_task();
    }
}

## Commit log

2025-09-13 add: Initial hardware prototype
    [1_1.kicad_sch, 2_2.kicad_sch, CONN-TH_10P-P1.27_HX-JN1.27-2X5P-ZZ-H4.9.step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]
2025-09-13 refactor: minor schematic visual changes
    [1_1.kicad_sch, 2_2.kicad_sch, usb_sp.kicad_pcb]
2025-09-17 add: include main file for the main firmware, minor doc and style fixes
    [eeprom.c, main.c, user.c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]
2025-09-18 fix: add missing cs line to spi bus
    [1_1.kicad_sch, 2_2.kicad_sch, usb_sp.kicad_pcb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]
2025-09-18 style: improve trace paths
    [usb_sp.kicad_pcb]
2025-09-18 fix: spi cs trace clearance
    [usb_sp.kicad_pcb]
2025-09-18 chore: update pdf schematic
2025-10-21 test commit
    [usb_sp.kicad_pcb]
2026-02-15 add developemnt board and fix issue related to dual i2c access
    [1_1.kicad_sch, 2_2.kicad_sch, HDR-TH_4P-HX-PH254-01-04-Z-L11.5.step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]
2026-02-15 ch32v203: usb relay queue implementation
    [usb_sp.kicad_pcb]
2026-02-15 hardware: add developemnt board and fix issue related to dual i2c access
    [1_1.kicad_sch, 2_2.kicad_sch, HDR-TH_4P-HX-PH254-01-04-Z-L11.5.step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]
2026-03-04 hardware: update KiCad design files
    [1_1.kicad_sch]
2026-03-05 fix (ch32v203): eeprom tlv implementation, replaces old raw implementation
    [eeprom.c]
2026-03-05 refactor (ch32v203): refactor usb relay queue by creating new helper functions
2026-03-05 fix (ch32v203): rework usb relay control-path in relay.c/relay.h by replacing descriptor-specific handlers with generic setup/nodata, new polling functionality and local descriptor relay
2026-03-05 refactor (ch32v203): add reset cause, adapt implementation to new relay and queue changes
    [main.c]
2026-03-07 feat (hardware): create production kicad project
    [1_1.kicad_sch, 2_2.kicad_sch, usb_sp_prod.kicad_pcb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]
2026-04-13 feat(website): add HID mouse decoding and trace export
2026-04-13 feat(ch32v203): add SPI bridge and capture support
2026-04-13 feat(ch572d): add SPI master bridge and EEPROM bus control
2026-04-13 feat(ch572d): add WebUSB commands for reset, capture and USB info
    [webusb_cmd_ch32_reset.c, webusb_cmd_get_active_usb_info.c, webusb_cmd_get_versions.c]
2026-04-13 feat(hardware): add TPS2121 power mux symbol and footprint assets
    [VQFN-HR-12_L2.5-W2.0-P0.50-BL.step]
2026-04-13 feat(hardware-dev): replace mode transistors with TPS2121 power mux
    [1_1.kicad_sch, 2_2.kicad_sch, usb_sp_dev.kicad_pcb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]
2026-04-13 feat(hardware-prod): replace mode transistors with TPS2121 power mux
    [1_1.kicad_sch, 2_2.kicad_sch, usb_sp_prod.kicad_pcb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]
2026-04-13 fix(website): render mouse trace from full capture history
2026-04-13 fix(ch32v203): serve patched descriptors from relay control path
2026-04-14 fix(ch32v203): store connected USB values without duplicating descriptors
    [main.c, user.c, user.h]
2026-04-17 fix(ch32v203): read USB strings with device LANGID
2026-04-18 fix(usbsp): validate active USB info offsets
    [spi_link.c, webusb_cmd_get_active_usb_info.c]
2026-04-20 fix(usbsp): remove capture-on-boot setting
    [eeprom.c, spi_link.c, user.c]
2026-04-20 fix(usbsp): clear missing imported USB strings
    [user.c]
2026-04-21 fix(ch572d): fix capture SPI polling
    [spi_link.c]
2026-04-21 fix(ch32v203): preserve original capture packet lengths
    [spi_link.c]
2026-06-07 feat(hardware): update board design assets
    [SOT-23-5_L3.0-W1.7-P0.95-LS2.8-BR.step, usb_sp_dev.kicad_pcb]
2026-06-07 fix(website): simplify USB configuration inputs
    [eeprom.c, spi_link.c, user.c]

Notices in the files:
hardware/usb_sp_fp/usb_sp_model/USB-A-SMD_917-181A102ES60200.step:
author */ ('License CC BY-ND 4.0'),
